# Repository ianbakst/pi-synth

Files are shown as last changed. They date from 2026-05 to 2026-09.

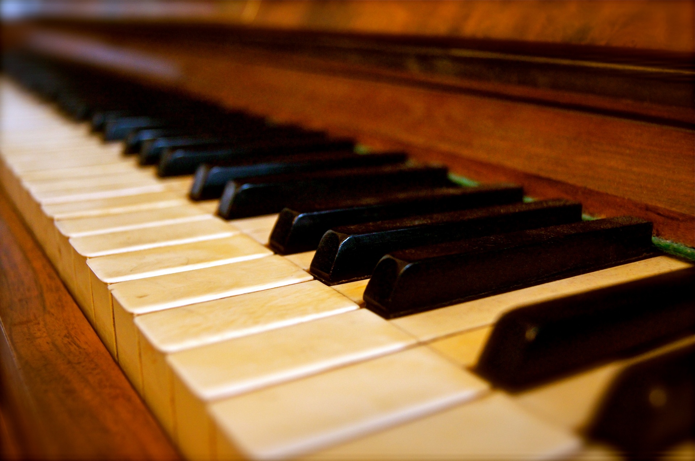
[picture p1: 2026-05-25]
src/synth_ui/assets/images/splash.jpg

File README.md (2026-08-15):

# pi-synth

A dedicated, hot-swappable MIDI instrument built on a Raspberry Pi 4. Multiple
audio engines — FluidSynth, sfizz, setBfree, Dexed, Pianoteq — run behind a common
interface and are switched at runtime from a 3.5" touchscreen. Audio flows over
JACK to a PCM5102A I2S DAC; a USB MIDI keyboard is bridged into JACK by
`a2jmidid`. The Python UI is a **control plane only** — it patches the JACK graph
and starts/stops engines; notes and samples never pass through Python.

On a non-Pi machine the UI runs windowed for development (`IS_PI` is auto-detected).

## Hardware

| Component | Part |
|---|---|
| SBC | Raspberry Pi 4 (64-bit, PREEMPT_RT kernel) |
| DAC | Teyleten Robot PCM5102A (I2S, `hifiberry-dac` overlay) |
| Display | 3.5" 800×480 touchscreen (ft5x06) |
| MIDI input | USB MIDI keyboard(s) — hot-plug supported |

## Provisioning: flash the custom image

The supported way to build a unit is to flash the **custom Raspberry Pi OS image**
built by pi-gen — it bakes in the RT kernel, the JACK/engine stack, all systemd
services, and this app, and boots straight to the UI with nothing to run by hand.

See **[os-image/README.md](os-image/README.md)**. In short: drop your prebuilt
RT kernel `.deb` in `os-image/kernel/`, then `cd os-image && ./build.sh`.

## Development

```bash
uv sync
uv run python -m synth_ui.main   # windowed UI (dev machine)
uv run pytest                    # tests
uv run ruff check src/           # lint
```

### Iterating on a running Pi

Once a unit is flashed, push app changes to it without reflashing:

```bash
./deploy.sh <pi-host>    # rsync src -> /home/synth/synth, run tests, restart synth-ui
```

## Project structure

```
src/synth_ui/          the control-plane app
  main.py              entry point (python -m synth_ui.main)
  config.py            paths, screen, ports, colors
  clients/             engine_manager (switches engines, patches JACK), engine
                       (Engine/ProcessEngine/ModHostEngine), jack_graph,
                       audio_devices, mod_host/synth clients, voice
  ui/                  pygame touchscreen UI (screens, components)
scripts/
  start-jack.sh        pick the ALSA card + exec jackd (jack.service's ExecStart)
systemd/               the 7 units (jack, a2jmidid, mod-host, synth-ui, ... )
instruments/voices.json  the voice manifest
os-image/              pi-gen custom image build (provisioning)
hardware/              DAC HAT / enclosure design files (Git LFS)
```

See [AUDIO_UPGRADE.md](AUDIO_UPGRADE.md) for the multi-engine audio architecture.

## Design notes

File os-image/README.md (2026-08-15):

# pi-synth OS image (pi-gen)

Builds a custom Raspberry Pi OS image that boots straight into the pi-synth
appliance — RT kernel, JACK/engine stack, all seven systemd services, and the UI
— with nothing to run by hand after flashing. This replaces the old `setup.sh`
provisioning of a stock Lite card.

It's a thin custom stage (`stage-pi-synth/`) layered on top of pi-gen's minimal +
Lite stages (`stage0`–`stage2`); the desktop stages 3–5 are never referenced.
pi-gen itself is a **build dependency `build.sh` fetches on demand**, pinned to an
exact commit on `bookworm-arm64`, into the gitignored `os-image/pi-gen/` — it is
never modified or committed; our stage lives here and is fed to pi-gen by
absolute path.

## Prerequisites

- **Docker** running (Docker Desktop on macOS; Apple Silicon builds the arm64
  target natively and fast — Intel falls back to qemu).
- Your **PREEMPT_RT kernel artifacts** harvested from a working RT board in
  [`kernel/`](kernel/) — layout and required filename are board-specific
  (`kernel8.img` for pi4, `kernel_2712.img` under `kernel/cm5/` for cm5). See
  [kernel/README.md](kernel/README.md).
- *(Optional)* **WiFi** — `cp wifi.env.example wifi.env` and fill in your SSID +
  password. If `wifi.env` is present, stage `07-wifi` bakes a NetworkManager
  profile into the image so the Pi joins WiFi on first boot. `wifi.env` is
  gitignored (it holds your password). Absent = no WiFi preconfigured; Ethernet
  still works.

## Build

```bash
git clone https://github.com/ianbakst/pi-synth.git
cd pi-synth
# harvest your RT kernel into os-image/kernel/ (see kernel/README.md)
cd os-image
./build.sh                       # pi4 (default): fetches + pins pi-gen, then builds
PI_SYNTH_BOARD=cm5 ./build.sh    # or build for the CM5 instead
```

`build.sh` clones pi-gen (pinned) into `os-image/pi-gen/` the first time — no
submodule, no `--recursive` needed.

The image lands in `os-image/pi-gen/deploy/` as `*-pi-synth.img.xz` (pi4) or
`*-pi-synth-cm5.img.xz` (cm5) — the board-specific name means both can be built
without one overwriting the other.

### Iterating

A full build is ~30–45 min. To resume after a failed/edited stage instead of
rebuilding from scratch:

```bash
CONTINUE=1 ./build.sh
```

To skip an expensive stage you've already built while iterating on a later one,
drop a `SKIP` file in it, e.g. `touch stage-pi-synth/02-audio-stack/SKIP`
(remove it before a real build). See the pi-gen README for the full
`SKIP`/`SKIP_IMAGES` workflow.

## Flash & verify

Flash `deploy/*-pi-synth.img.xz` with Raspberry Pi Imager (or `dd`). On first
boot it should come up on the touchscreen with no manual steps. Sanity checks
over SSH (`synth` / password from `config`):

```bash
uname -v                                   # contains PREEMPT_RT
aplay -l | grep -i hifiberry               # DAC present
systemctl is-active jack a2jmidid mod-host synth-ui   # all active
```

Then confirm a USB keyboard plays and switching voices works. For the realtime
floor: `cyclictest -m -Sp99 -i200 -l100000`, and watch JACK's xrun counter over a
sustained voice-switching session.

## What the stage does (ported 1:1 from the old setup.sh)

| Stage | Responsibility |
|---|---|
| `00-base-packages` | apt packages + jackd2 RT-limits debconf preseed |
| `01-realtime-kernel` | install harvested RT kernel (board-specific filename, see `PI_SYNTH_BOARD`) + modules, `depmod` |
| `02-audio-stack` | build + install mod-host and sfizz (LV2) from source |
| `03-boot-config` | `config.txt` (HiFiBerry DAC, disable BT/onboard audio, HDMI audio) + `cmdline.txt` (isolate cores 1,2,3; quiet boot) |
| `04-pi-synth-app` | vendor app to `/home/synth/synth`, dirs, `default.sf2`, sudoers |
| `05-services` | install 7 units; enable always-on ones; mask stock fluidsynth |
| `06-system-tuning` | RT limits, RAM-only journald, no swap, disable jitter services |

CPU governor and IRQ affinity are applied at runtime by `cpu-performance.service`.

## Configuration

Edit [`config`](config): first user (`synth`), hostname, locale/timezone,
WiFi country, SSH pubkey, image compression. The `synth` username is load-bearing
(hardcoded in the units and `config.py`) — don't change it.

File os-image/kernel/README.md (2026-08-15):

# RT kernel artifacts

The image bakes a **PREEMPT_RT kernel harvested from a working RT board** (there
is no official prebuilt RT kernel to download for Raspberry Pi OS). Drop the
harvested files here — they are **not** committed (`os-image/.gitignore` excludes
them at any depth under `kernel/`; they're large and board-specific). Use Git LFS
if you want them tracked.

Layout is per-board, selected by `PI_SYNTH_BOARD` (`pi4` default, or `cm5`) when
running `../build.sh` — see its usage comment. **pi4** keeps the original flat
layout (unchanged, for backward compatibility); **cm5** lives in its own
subdirectory since it needs a different kernel filename and is a different SoC
generation (BCM2712, not BCM2711 — a from-scratch RT build, not a re-harvest of
the pi4 one).

## Expected layout

```
kernel/
├── kernel8.img            # pi4 RT kernel image                 (required for pi4)
├── modules/<KVER>/        # pi4 /lib/modules/<KVER> tree         (required for pi4)
├── dtb/*.dtb               # pi4 device trees                    (optional)
├── overlays/*.dtbo         # pi4 overlays                        (optional)
└── cm5/
    ├── kernel_2712.img     # cm5 RT kernel image                 (required for cm5)
    ├── modules/<KVER>/     # cm5 /lib/modules/<KVER> tree         (required for cm5)
    ├── dtb/*.dtb            # cm5 device trees                    (optional)
    └── overlays/*.dtbo      # cm5 overlays                        (optional)
```

`<KVER>` is your kernel version string (`uname -r` on the board), e.g.
`6.12.30-rt-v8+` (pi4) or `6.12.96-v8-16k+` (cm5 — note PREEMPT_RT doesn't
always appear in the version *string* itself; confirm with `uname -v` instead,
which should contain `PREEMPT_RT`). The modules tree **must** match the kernel
image, or the kernel boots but half its drivers won't load — always key off
`uname -r`.

Note the boot filename genuinely differs by SoC generation, not just by
convention: BCM2711-and-earlier (pi4) boards default to `kernel8.img`;
BCM2712 (Pi 5/CM5-generation) boards default to `kernel_2712.img`. Installing
under the wrong filename means the firmware silently keeps booting whatever it
already had — stage `01-realtime-kernel` installs to the correct name per
board automatically, but a manual local install (to test-boot before
harvesting) needs the right name too.

## How to harvest (run on your Mac)

### pi4 (flat layout, unchanged)

```bash
PI=synth@192.168.1.125                 # your Pi's user@IP
KVER="$(ssh "$PI" uname -r)"
cd os-image/kernel

scp "$PI:/boot/firmware/kernel8.img" ./kernel8.img
mkdir -p dtb overlays
scp "$PI:/boot/firmware/*.dtb"           ./dtb/
scp "$PI:/boot/firmware/overlays/*.dtbo" ./overlays/
# rsync (not scp -r): copies the dangling build/source symlinks safely
rsync -a --exclude=build --exclude=source "$PI:/lib/modules/$KVER" ./modules/
```

### cm5 (subdirectory layout)

```bash
PI=synth@192.168.1.126                 # your CM5's user@IP
KVER="$(ssh "$PI" uname -r)"
mkdir -p os-image/kernel/cm5
cd os-image/kernel/cm5

scp "$PI:/boot/firmware/kernel_2712.img" ./kernel_2712.img
mkdir -p dtb overlays
scp "$PI:/boot/firmware/bcm2712*.dtb"    ./dtb/
scp "$PI:/boot/firmware/overlays/*.dtbo" ./overlays/
rsync -a --exclude=build --exclude=source "$PI:/lib/modules/$KVER" ./modules/
```

## How it's used

Stage `01-realtime-kernel` overwrites the board's default kernel filename
(`kernel8.img` for pi4, `kernel_2712.img` for cm5 — the base image already sets
`arm_64bit=1` with no custom `kernel=`, so the firmware loads the default by
name — no `config.txt` change needed) with your RT image, installs the modules
tree to `/lib/modules/<KVER>`, refreshes the dtbs/overlays if present, and runs
`depmod -a <KVER>` in-chroot to regenerate dependency metadata.

To confirm after flashing: `uname -v` on the booted board should contain
`PREEMPT_RT`, and `lsmod` should show your drivers loading.

## Custom kernel name?

If the board's `config.txt` set a custom `kernel=` (check with
`grep kernel= /boot/firmware/config.txt`), the harvested image may not be named
`kernel8.img`/`kernel_2712.img` — stage `01` still installs the single `*.img`
it finds in the board's kernel directory under that board's expected default
name, which the firmware boots by default absent a `kernel=` override.

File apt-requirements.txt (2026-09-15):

python3-pygame
fluidsynth
jackd2
a2jmidid
# Kept for its LV2 bundle (/usr/lib/lv2/b_synth), which IS the Hammond now.
# The standalone binary it also installs is no longer run — setbfree.service
# was retired when the organ moved into mod-host. Do not drop this package.
setbfree
build-essential
cmake
libsndfile1-dev
libjack-jackd2-dev
liblilv-dev
libreadline-dev
# Keep in sync with os-image/stage-pi-synth/00-base-packages/00-packages — that
# list provisions a fresh image, this one is what deploy.sh installs onto a
# running board. They had drifted: the LV2 plugin packages below were only in
# the image list, so a deployed-to board could be missing the plugins the voice
# catalog names.
# LV2 plugins: effects, and the mda/Calf instruments in voices.json.
calf-plugins
zam-plugins
x42-plugins
mda-lv2
# lv2ls / lv2info: the UI greys out voices whose plugin isn't installed, and
# verify_voices --inspect reads a plugin's control symbols + patch properties.
lilv-utils
# --- Instrument plugins ---------------------------------------------------
# amsynth: a two-oscillator analog model. This is the one for the 80s brass
# poly (the Van Halen "Jump" sound is an Oberheim OB-Xa: detuned saws, fast
# filter envelope). mda JX10 can approximate it; amsynth gets much closer and
# ships presets.
amsynth
# zynaddsubfx-lv2: additive/subtractive/pad engine with a large preset bank —
# breadth for pads, bells and leads that the mda and Calf synths don't cover.
zynaddsubfx-lv2
# Level calibration (synth_ui.tools.calibrate_levels).
# aplaymidi (alsa-utils) plays the passage; jack-smf-player would be the
# direct route but jack-smf-utils is no longer packaged for Debian.
jack-capture
alsa-utils
ffmpeg

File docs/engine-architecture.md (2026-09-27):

# Engine architecture & audio graph

How the pi-synth control plane switches instruments and routes audio, and the
roadmap to get there. This reconciles the design in `.claude/plan.md` with the
realities of the running system (systemd-managed RT engines, mod-host, the
harvested-kernel image).

## Principles (unchanged from the design)

- **No Python in the note/audio path.** Notes flow `a2jmidid`/`ttymidi` (USB /
  DIN) `→ JACK → engine → DAC` in realtime-thread space. Python only issues
  *control-plane* actions:
  start/stop an engine, load a preset, and patch the JACK graph.
- **The app never manages JACK or RT scheduling itself.** JACK, mod-host, and
  a2jmidid run as systemd services (see `../systemd/`). Engines get their RT
  priority + core pinning from their unit files (`chrt`, `taskset`,
  `LimitRTPRIO`), never from Python.

## Key decision: switch at the systemd level, orchestrate in Python

The design doc had Python `Popen` the engine *and* forbade Python from setting RT
priority — a contradiction (nobody grants the spawned engine `chrt -f 80`). We
resolve it by keeping engines as **systemd services** and putting only the
*orchestration* in Python:

- `ProcessEngine.start()` → `systemctl start <unit>` (not `Popen`). The unit file
  supplies RT priority/affinity/memlock.
- `ModHostEngine.start()` → `add <uri> <instance>` over mod-host's socket
  (mod-host is already an RT JACK client).
- The `Engine` interface, `ENGINE_REGISTRY`, connect-before-disconnect ordering,
  panic-before-teardown, and readiness polling all live in Python.

This is not slower in any way that matters: a switch's cost is dominated by the
engine's own cold-start (soundfont load, JACK port registration); `systemctl`
adds tens of ms of orchestration that is inaudible next to that, and steady-state
audio latency is identical. systemd also buys supervision, journald logging, and
declarative limits. So the choice is made on robustness, not speed.

## CPU core allocation (Pi 4, 4 cores)

One purposeful role per core. Cores 1,2,3 are isolated
(`isolcpus=1,2,3 nohz_full=1,2,3 rcu_nocbs=1,2,3` in `cmdline.txt`); core 0 runs
the normal scheduler.

| Core | Role | Isolated | Pinned via |
|---|---|---|---|
| **0** | OS + UI + all general IRQs | no | `synth-ui.service` `taskset -c 0` `Nice=5`; `cpu-performance.service` sets IRQ mask 1 |
| **1** | JACK backend (audio heartbeat) + MIDI bridges + audio IRQ | yes | `jack.service` / `a2jmidid.service` / `ttymidi.service` `taskset -c 1`; audio IRQ steered by `cpu-performance.service` |
| **2** | Active instrument engine | yes | `fluidsynth-engine`/`setbfree`/pianoteq `taskset -c 2`; `mod-host` also uses this core (see below) |
| **3** | Currently: mod-host overflow. Later: effects | yes | `mod-host` `taskset -c 2,3` today; a *second* mod-host for effects — **Phase 3, not yet built** — would also want this core |

Deliberately **not** core 0: that's where `isolcpus`/`nohz_full` route every general
IRQ, kernel housekeeping thread, and the UI, on purpose — audio sharing it would
be exposed to exactly the noise the isolation exists to prevent, and risks
starving the same core SSH/D-Bus run on. Confirmed not worth it on hardware (see
"Active instrument engine" below).

**Why this, and what it buys:** the chain `engine → effects → DAC` is *serial*, so
separate cores don't run stages in parallel — the win is **jitter isolation and
headroom** (each stage uncontended → lower buffers, fewer xruns under sustained
load), not throughput. RT-correct for an instrument.

**"Active instrument engine" is enforced to mean exactly one process, always.**
mod-host used to be always-on (enabled at boot like jack/a2jmidid). Hardware
validation found that having it resident on core 2 at the same time as another
active engine (e.g. fluidsynth) causes continuous JACK XRuns — `journalctl -u
jack | grep -c XRun` kept climbing indefinitely even with both engines fully
idle, because two `chrt -f 80` RT clients were contending for one isolated core
every single 2.67ms period. Stopping one of the two immediately took the xrun
count to a steady 0. Fix: mod-host is now on-demand, exactly like
`fluidsynth-engine`/`setbfree` — `ModHostEngine.start()`/`stop()`
(`src/synth_ui/clients/engine.py`) start/stop `mod-host.service` around the
add/remove-plugin socket calls, and the unit is no longer `systemctl enable`d
at boot (`os-image/stage-pi-synth/05-services`) nor `PartOf=jack.service` (that
would have force-restarted it — i.e. started it even when it shouldn't be
running — on every audio-device change).

**mod-host caveat:** mod-host processes all its plugins in one thread, so a single
mod-host can't split instrument from effects onto separate cores. **Core 3's role
has changed from the original plan**: rather than sit idle waiting for Phase 3,
the instrument mod-host now spans cores 2+3 (`taskset -c 2,3`), because a large
SFZ's sample streaming/decode work was contending with JACK's own callback
thread for core 2 alone — a real, measured problem (below), not a hypothetical
one. **This means Phase 3's plan needs revisiting**: a second mod-host wanting
sole use of core 3 for effects would recreate the exact single-core contention
this fix just solved. Options when that's built: give effects core 3 back and
accept the instrument-side regression, find a third core to shuffle things onto,
or reconsider whether effects need a dedicated core at all. Not decided — flag
this when Phase 3 effects routing actually starts.

**Validated on hardware:**
- `journalctl -u jack | grep -c XRun` flat at 0 with the active instrument engine
  alone on core 2, sustained idle.
- mod-host on core 2 alone, streaming a large SFZ (641 regions) under sustained
  play: ~180 xruns/min despite only ~40-60% CPU — confirming RT audio is
  deadline-per-callback bound, not average-utilization bound; CPU headroom does
  not predict xrun-freedom when a core is shared or contended.
- Same scenario, mod-host expanded to cores 2,3 (`taskset -c 2,3`, still no
  `chrt`): ~65 xruns/min — real improvement, not a full fix. The remainder was
  attributed at the time to first-touch SD sample reads; the CM5 measurements
  below found two causes that sit *behind* those reads rather than being them.
- Re-adding `chrt -f 80` to mod-host on 2,3 was tested and made things
  dramatically worse (~14,500 xruns/min, audible buzzing): it raised mod-host's
  decode threads above JACK's own callback-thread priority, causing them to
  preempt it — a priority inversion. Confirms mod-host should stay affinity-only,
  no `chrt`, matching the SIGKILL/RCU-stall wedge found earlier under heavy load.

**Remaining sfizz xruns, CM5 (2026-09).** Test: a fixed two-minute pedalled
Salamander passage (1,440 notes, seeded) sent through `Midi Through` with the
DAC disconnected, counting JACK `Process error` cycles.
- **Priority inversion, 92 xruns → 2-25.** sfizz raises its own disk-streaming
  threads to `SCHED_RR 50` when `RLIMIT_RTPRIO` allows it. mod-host had
  `LimitRTPRIO=80`, so it did, and every JACK client thread in mod-host runs at
  `FIFO 5` (jackd's default `-P 10`, minus 5 — the `chrt -f 90` in
  `start-jack.sh` lifts only jackd's idle main thread; its audio thread is at
  10). Each note past its preload had a loader decoding the rest of the sample
  ahead of every audio thread on cores 2-3. `LimitRTPRIO=10` makes sfizz's
  request fail quietly.
- **Page faults in real-time threads, 2-25 → 0.** Every remaining xrun lined up
  with a page fault in a mod-host real-time thread (sampled per thread every
  100 ms), and every such fault with an xrun. The loaders' constant mapping and
  unmapping holds the mmap lock that even a minor fault needs. mod-host doesn't
  `mlockall`, so `scripts/mlockall_preload.c` does it via `LD_PRELOAD`: five
  runs, zero xruns, zero faults. Cost: mod-host's memory stays at its
  high-water mark (~1.65 GB with Salamander, ~2 GB left free).

Still to validate: `cyclictest -m -Sp99 -i200 -l100000` on cores 1,2,3 for the
raw RT floor, and the xrun counter over a sustained voice-*switching* session
(not just idle) now that mod-host's lifecycle changed.

## The JACK graph (data plane)

```
 a2j:<keyboard capture>   (USB) ─┐
                                 ├──MIDI──▶ [ velocity filter ]  ← optional, lazy
 ttymidi:MIDI_in     (5-pin DIN) ─┘                   │
                                                      ▼
                                          <active engine>:midi_in
                                                  │ audio out
                                                  ▼
                              [ effects rack (mod-host) ]   ← optional, persistent
                                         │
                                         ▼
                                 system:playback_1/2  (HiFiBerry DAC)
```

### MIDI ingress: two transports, one rule

USB and DIN are physically different transports and need different bridges —
`a2jmidid` lifts ALSA-seq hardware ports into JACK, `ttymidi` (mod-audio's
`mod-ttymidi`) reads the UART0 byte stream. Both are C, RT-scheduled, on core 1;
neither puts Python in the note path.

This also closed a latent bug. `a2jmidid -e` does **not** mean "hardware only" —
it is opt-*in* for hardware ports and still exports software ALSA-seq clients
alongside them. The previous rule ("any `a2j:` port whose name contains
`capture`") therefore also matched ALSA's `Midi Through` loopback and wired it
into the active instrument on every voice switch. Harmless — nothing feeds it —
but junk in the graph; the physical flag excludes it.

What keeps that from becoming a pile of special cases is that the control plane
never names either of them. Both bridges register their JACK ports as
`JackPortIsPhysical | JackPortIsTerminal` — the claim "this is a real jack on the
box, not a software port" — so `JackGraph.keyboard_midi_sources()` matches on
exactly that: **a physical MIDI source port**. `EngineManager._wire()` patches
every one of them to the active instrument, so both keyboards play the current
rig, and a third transport (a second DIN, BLE/RTP-MIDI) needs no code change.

**Confirmed on the CM5** (2026-09-02), which is why the config looks like it
does: with `dtparam=uart0=on`, `/dev/ttyAMA0` appears as `root:dialout` (so the
`synth` user reaches it via the group pi-gen already grants — no unit-level
group grant needed), GPIO14/15 mux to `TXD0`/`RXD0`, and the RP1 UART accepts a
true 31250 baud through `TCSETS2`/`BOTHER` — verified against a 38400 control
request, so no `midi-uart0-pi5` clock overlay is needed. Note `stty` *cannot*
express 31250 (it errors "invalid argument"); that's a coreutils limitation, not
a hardware one, so don't read it as a fault.

**Not yet confirmed:** bytes on the wire. No MIDI-out gear was on hand when this
landed, so the DIN jack, its opto-isolator, and the achieved divisor are unproven
end to end. Everything up to and including "the JACK port exists and the UI
patches it into the active rig" is verified. See the deferred check at the bottom
of this section.

The DIN jack is wired to UART0 RX (GPIO15) only — MIDI IN, no OUT.
`ttymidi:MIDI_out` exists but is left unconnected. Setup lives in
`os-image/stage-pi-synth/03-boot-config/00-run.sh` (enable `uart0`, and keep the
kernel's serial console *off* those pins) and `systemd/ttymidi.service`
(31250 baud, set directly via `BOTHER`/`TCSETS2` rather than with the
`midi-uart0` clock-fudge overlay).

**Deferred check — do this when a MIDI controller is available.** Play into the
DIN jack and confirm notes sound through the active rig. If they don't, isolate
with `python3 ~/synth/scripts/midisniff.py` (a `BOTHER`-mode raw byte dump —
`stty` can't set this rate): note-on triples that track your playing mean the
wire is fine and the fault is above it; garbage means the divisor is off after
all, so add
`dtoverlay=midi-uart0-pi5` and switch `ttymidi.service` to `-b 38400`; silence
means wiring or the opto-isolator, DIN pins 4/5 first. Without a controller, a
jumper from GPIO14 to GPIO15 loops TX back to RX and exercises the same path —
but check it won't fight the opto's output stage on that net first.

There is a simpler shape available later: the kernel's `snd_serial_generic`
driver (`compatible = "serial-midi"`) would make the DIN port a real ALSA rawmidi
card, so `a2jmidid` alone would carry both transports and `ttymidi.service` could
be deleted. It is not enabled in `bcm2711_defconfig`/`bcm2712_defconfig` and so is
absent from the harvested RT kernel; taking it would mean a kernel rebuild plus a
hand-written overlay. Worth doing on the next kernel build, not before — and the
port rule above already covers that world unchanged, since the DIN port would
then simply appear under `a2j` as physical.

Per-engine JACK identities (discover with `jack_lsp` / `jack_lsp -t` on the Pi —
do not hardcode without checking):

| engine | kind | MIDI in | audio out |
|---|---|---|---|
| fluidsynth | process (`fluidsynth-engine.service`) | `fluidsynth*:midi*` | `fluidsynth*:l/r` (needs `audio.jack.autoconnect=1`) |
| setBfree | process (`setbfree.service`) | `setBfree:midi_in` | `setBfree:out_left/right` |
| sfizz / dexed | mod-host plugin (`mod-host.service`) | `mod-host:midi_in` | mod-host plugin audio out |
| pianoteq | process (future `pianoteq.service`) | `Pianoteq*:midi*` | `Pianoteq*:out_*` |

**Known gap this design closes:** nothing currently connects a mod-host
instrument's *audio* output to `system:playback`, and `fluidsynth -a jack` does
not autoconnect by default — so mod-host voices are likely silent today and
fluidsynth relies on luck. Audio patching becomes an explicit EngineManager
responsibility (Phase 2), and fluidsynth gets `audio.jack.autoconnect=1` now
(Phase 1).

### Fixed velocity — `VelocityFilter`

A rig can play every note at one velocity instead of as struck
(`Rig.fixed_velocity`, toggled from the rig editor's header). Since notes never
pass through Python, that means rewriting a byte of every note-on in the RT
path, so it is an LV2 plugin in mod-host — x42's
`midifilter#velocityscale`, which ships in `x42-plugins` (already in
`00-packages`; nothing new to build).

It is the MIDI-side mirror of the master chain: a single-purpose stage the user
never assembles, sitting at the head of the path rather than the tail, at
mod-host instance **100** (instruments 0-9, effects 10-89, master 90+, MIDI
filters 100+). `EngineManager._midi_sources()` answers "what feeds the
instrument" the way `_sinks()` answers "where does its audio go", so neither
`_wire` nor `_unwire` has to know whether a filter exists.

Three decisions worth not re-litigating (the reasoning is in
`clients/velocity_filter.py`):

- **Loaded lazily**, unlike the master chain — a board that never uses this
  never carries the plugin. The master chain is always needed; this isn't.
- **Off is identity parameters, not removal.** `onmin=1, onmax=127` is an exact
  identity in midifilter's arithmetic, and `onmin == onmax == V` pins every
  note-on to V. Removing the plugin on every toggle would rebuild the
  keyboard→instrument leg each time, and while both the direct and the filtered
  edge exist every note sounds twice.
- **`bypass` is not used for it.** mod-host's bypass copies input buffers to
  output, which is defined for audio; whether it forwards MIDI is not something
  to bet the keyboard on.

**Not yet measured on hardware:** the added latency. The filter is a second JACK
client in series, but both it and the instrument live in the same mod-host
process and JACK runs serial clients in dependency order within one period, so
the expected cost is ~0 — worth confirming with `tools/midi_latency.py` before
trusting it in a set, given how much trouble MIDI latency has already been on
this box (see the FP-10 note in CLAUDE.md).

## Audio device selection (which card JACK opens)

A *different* discovery layer from `JackGraph`: which physical sound card jackd
opens. JACK binds one device at startup and presents uniform `system:playback_*`
ports regardless — so the graph patching above is card-agnostic; only jackd's
startup device changes.

- **`AudioDevices`** (`clients/audio_devices.py`) enumerates ALSA playback cards
  from `aplay -l` by stable id (`hw:<id>`, never index), and resolves the
  effective device by precedence: **valid saved choice → HiFiBerry → first card →
  none**.
- **`scripts/start-jack.sh`** is `jack.service`'s ExecStart. It applies that same
  precedence at boot and falls back to jackd's **dummy backend** if no card is
  present — so jackd (and the UI) always come up and the user can recover from a
  missing/renamed card.
- Selection persists in `~/.synth-audio-device` (config `AUDIO_DEVICE_FILE`),
  written by the UI. Absent = auto-detect (the out-of-box default).
- Changing the card = **restart jackd** (not a live patch), which rebuilds the
  stack: `mod-host`/`a2jmidid` are `PartOf=jack.service` so they cycle with it;
  `synth-ui` is `Wants=` (not `Requires=`) so the control-plane UI survives the
  restart it triggered, then reloads the active voice to re-patch.
- **Next:** a UI "Audio" screen (list cards → select → write file → `sudo
  systemctl restart jack.service` → reload voice; sudoers already scoped for it),
  and sample-rate / buffer-size tuning on the same screen.

## The Python layer (target shape)

```
src/synth_ui/clients/
├── jack_graph.py     # JackGraph: discover ports + connect/disconnect (subprocess
│                     #   jack_lsp/jack_connect — zero new deps; swappable for
│                     #   python-jack later). connect-before-disconnect lives here.
├── engine.py         # Engine ABC, ProcessEngine (systemctl), ModHostEngine (socket)
├── engine_manager.py # EngineManager: ENGINE_REGISTRY, switch_to(), panic ordering,
│                     #   MIDI + AUDIO patching. Public API (load_voice/list_presets/
│                     #   select_preset/set_gain/is_connected) stays stable for the UI.
├── mod_host_client.py  # (exists) mod-host socket protocol
├── synth_client.py     # (exists) FluidSynth TCP shell
└── voice.py            # (exists) Voice + manifest
```

`Engine` interface (adds `audio_out_ports` and `load` to the design's version):

```python
class Engine(ABC):
    key: str                       # JACK-source identity for same-source detection
    def start(self) -> None: ...
    def stop(self, timeout=2.0) -> None: ...
    def is_ready(self) -> bool: ...        # poll: ports present in the JACK graph
    def panic(self) -> None: ...           # all-notes-off, best effort, before teardown
    def load(self, voice: Voice) -> bool: ...   # load SF2/SFZ/patch into the running engine
    @property
    def midi_port(self) -> str: ...
    @property
    def audio_out_ports(self) -> list[str]: ...
```

**Reality-driven divergence:** sfizz and dexed are *not* separate engines — they
share mod-host's single plugin slot and its stable JACK ports. They collapse into
one `ModHostEngine` whose `load(voice)` swaps the plugin (remove+add if the URI
differs) and `patch_set`s the instrument file (an LV2 patch property — sfizz's
SFZ path is atom-based, not a control port; `param_set` silently no-ops on it).
Switching sfizz↔dexed is therefore an
in-mod-host swap with **no JACK re-patch** (the ports don't move). The manager
uses `engine.key` (`fluidsynth`/`setbfree`/`pianoteq`/`modhost`) to decide
in-place reload vs. full switch.

`EngineManager.switch_to(voice)` (full switch path):
1. `new.start()`; poll `new.is_ready()` with a bounded timeout → surface a clear
   UI error on timeout.
2. `new.load(voice)`.
3. `graph.connect(keyboard_midi → new.midi_port)` and
   `graph.connect(new.audio_out_ports → sink)` — **before** touching the old one.
   (`sink` = effects-rack input if effects are loaded, else `system:playback`.)
4. If an engine was active: `old.panic()`, then disconnect old MIDI/audio ports
   **except any shared with new** (protects mod-host's shared ports), then
   `old.stop()`.

Same-`key` load (e.g. fluidsynth SF2 → SF2) skips all patching: just
`active.load(voice)`.

## Effects rack (mod-host) — `EffectsRack`

**Resolved:** effects run in the *same* mod-host instance as the active
instrument (cores 2+3), not a second process on its own core. The original
two-instance plan (`systemd/mod-host-fx.service`, socket 5556, core 3) is
superseded — reasoning, not just a resource conflict:

- **Separate cores never bought parallelism here, because there wasn't any to
  buy.** Instrument → effects is a serial *data dependency*: effects can't
  start processing a period until the instrument's output for that period
  exists. Total compute (instrument + effects) has to fit in one ~2.67ms
  deadline no matter which core(s) either stage runs on — there is no
  independent work to overlap. Contrast with why cores 2+3 *did* help the
  instrument alone: mod-host's LV2 "worker" threads (e.g. sfizz's own sample-
  streaming) are genuinely independent of that period's callback and benefit
  from a free core to run on. Effects DSP has no such independent piece — it's
  on the critical path by definition.
- Practical upshot: a second mod-host on its own core would not have isolated
  effects from instrument-side latency the way the original plan assumed. It
  would have added a second full LV2-world-scan cold-start (the exact
  readiness race already fixed once for the instrument mod-host) and a second
  process that could wedge, for a benefit that doesn't materialize for this
  specific pipeline shape.
- **This also resolves one of the two hardware unknowns below**: mod-host's
  per-instance port-naming convention (`effect_<instance>`) is no longer a
  *separate* fx-mod-host question — it's the same convention already confirmed
  on hardware for the instrument mod-host (`effect_0:control` /
  `effect_0:out_left/right`, found while debugging sfizz). Effects loaded at
  instances 10+ in the same process follow the identical naming; nothing new
  to verify there. The *other* unknown (§ below) — whether a real effect
  plugin's DSP fits the shared budget without pushing xruns up — is still a
  hardware question, now the only one.

`clients/effects_rack.py` (`EffectsRack`) manages the chain:

- Effect plugins live at mod-host instances **`10+`** (instruments use `0–9`),
  loaded once and **persistent across instrument switches**.
- `add(uri)` appends to the chain and `_rechain()`s: `fx[0].out → fx[1].in → … →
  fx[N].out → system:playback`. It tears down its prior wiring first (tracked in
  `_wired`) so a stale "old last → DAC" edge never lingers. `remove`/`clear`
  likewise re-chain. Python only patches; DSP is in mod-host.
- `input_ports()` (first effect) / `output_ports()` (last effect) let the manager
  route `active_instrument.out → rack.input`; the rack→DAC leg never moves.
- **Watch the xrun counter as each effect is added** — this is now the real
  budget check, since effects share the instrument's cores and its per-period
  deadline. Add one at a time, measure, don't assume a chain that worked with
  N-1 effects still has headroom for N.
- **Not** running `mod-ui` (MOD's web pedalboard editor) — too heavy/jittery for a
  touchscreen appliance. Drive mod-host directly.

**One open question left that needs the board:** does real effect DSP (a
reverb, an EQ, a compressor) actually fit the shared per-period budget
alongside a loaded instrument, and how many/how heavy before xruns climb? No
longer an architecture question — just needs measuring on real hardware, the
same way the instrument-alone budget was measured tonight (~180 → ~65
xruns/min moving 2→cores 2,3; a similar live test applies here per effect
added).

**Still deferred, now purely because nobody's built it yet, not because of an
open unknown:** `EngineManager` routing (instrument → rack → DAC, and
re-wiring the instrument when the rack goes empty↔non-empty) and the UI
effects screen — in progress, see the plan for "Wire the effects rack into
EngineManager + UI". `mod-host-fx.service` (the old, superseded two-instance
design) has been deleted.

## Startup: a working instrument on boot

`HomeScreen` already loads the restored voice on startup — but only if
`~/.synth-state` exists, so a freshly flashed card plays nothing until you tap a
voice. Fix: fall back to a configured `DEFAULT_VOICE` (the fluidsynth "General
MIDI" voice — its `default.sf2` is guaranteed present in the image, and with
autoconnect its audio reaches the DAC). So: boot → splash → default GM voice
loads → keyboard plays, no interaction needed.

## Phased roadmap

**Phase 1 — working instrument on startup (low risk, no hardware needed to write):**
- `fluidsynth-engine.service`: add `-o audio.jack.autoconnect=1`.
- `DEFAULT_VOICE` in config; `app.py` uses saved-state-or-default.
- Rebuild → boot → GM piano playable with no touchscreen interaction.

**Phase 2 — engine-over-systemd + full audio graph (needs the Pi in the loop):**
- `JackGraph`, `Engine`/`ProcessEngine`/`ModHostEngine`, `EngineManager` rework
  with MIDI **and** audio patching + panic + connect-before-disconnect.
- Fixes mod-host (sfizz/dexed) silence by explicitly wiring their audio to the
  DAC. Retire `scripts/engine-manager.sh` / `midi-connect.sh` (Python
  orchestrates via `systemctl` + `jack_*`).
- *Validated on hardware:* found and fixed mod-host being always-on causing
  continuous core-2 XRuns (see "Active instrument engine" note above) — it's
  now on-demand like the other engines.
- Still to validate: no gap on switch, panic silences held notes, sustained
  *switching* produces no xruns (idle is now confirmed clean; switching load
  hasn't been re-tested since the mod-host lifecycle change).

**Phase 3 — effects rack** (see "Effects rack" above):
- *Done (increment 1):* effect LV2 packages in `00-packages`
  (`calf-plugins`, `zam-plugins`, `x42-plugins`, `mda-lv2`); `mod-host-fx.service`
  (core 3, installed not enabled); `EffectsRack` class + tests.
- *Needs the board:* confirm the fx mod-host client name and the effect
  audio-port naming (the two open questions above), then wire `EngineManager`
  routing (instrument → rack → DAC) and the UI effects screen.
- Watch the xrun budget on core 3 as effects are added.

## Engine build status (image `02-audio-stack`)

- **sfizz** — LV2 plugin built from `sfztools/sfizz-ui` (NOT `sfztools/sfizz`,
  which is only the core lib + a JACK client we don't use). Verified on hardware:
  installs `/usr/local/lib/lv2/sfizz.lv2`, URI `http://sfztools.github.io/sfizz`
  (matches `_MODHOST_PLUGINS` in `clients/engine.py`).
- **Dexed** — **not built yet.** The two DX7 voices in `voices.json` will fail to
  load until a Dexed LV2 build is added to `02-audio-stack` (same
  verify-on-hardware-then-codify path sfizz took). Its URI/param symbol in
  `_MODHOST_PLUGINS` (`https://asb2m10.github.io/dexed`, `sysex_file`) are
  unconfirmed until then.

## Open questions (from the design, still open)

- Exact mod-host audio-out port names — confirm with `jack_lsp -t` on the Pi
  before wiring Phase 2 audio.
- `is_ready` timeout per-engine vs global (Pianoteq starts slower than sfizz).
- Whether to add `pianoteq.service` (proprietary; only if/when installed).

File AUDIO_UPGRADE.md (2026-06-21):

# Upgrading Audio Quality — From SoundFonts to Professional Sound

## Context

This document is for a MIDI instrument built on a Raspberry Pi 4 with:
- PREEMPT_RT kernel (6.12.x, built from `rpi-6.12.y` with `bcm2711_rt_defconfig`)
- PCM5102 I2S DAC on ALSA device `hw:2`
- Audio pinned to CPU cores 2-3 with RT priority 80
- USB MIDI keyboard input
- Touchscreen UI (Pygame) on cores 0-1 for voice selection
- FluidSynth currently running as the audio engine via systemd service
- Communication between UI and audio engine via TCP

The SoundFont-based setup works but sounds amateur. This document covers upgrading to professional-quality sound.

## Architecture Change

Currently: FluidSynth is the only audio engine, controlled via TCP on port 9800.

New approach: Multiple audio engines, each specialized for what it does best. A manager process starts the right engine for the selected voice category.

```
Voice selected on touchscreen
    │
    ▼
Engine Manager (script/service)
    │
    ├── Piano/Sampled instruments → sfizz
    ├── Hammond Organ → setBfree
    ├── FM Synth / DX7 sounds → Dexed (via mod-host)
    ├── General MIDI / fallback → FluidSynth
    └── Physical modeling piano → Pianoteq (commercial)
```

**Critical design rule (unchanged):** The audio engine runs independently of the Python UI. If the UI crashes, audio continues. The architecture from CLAUDE.md still applies — the UI sends commands, it never manages the audio process directly.

## Engine 1: sfizz (Sampled Instruments)

sfizz is an SFZ-format sample player. SFZ is dramatically better than SoundFont — more velocity layers, round-robin, release samples, sympathetic resonance, legato transitions.

### Install

```bash
sudo apt-get install sfizz
```

If not available via apt:

```bash
sudo apt-get install build-essential cmake libsndfile1-dev libjack-jackd2-dev
git clone --recursive https://github.com/sfztools/sfizz.git
cd sfizz
mkdir build && cd build
cmake -DCMAKE_BUILD_TYPE=Release ..
make -j4
sudo make install
```

### Run with ALSA

```bash
chrt -f 80 taskset -c 2,3 sfizz_jack &
# or if using ALSA directly, sfizz can be loaded as an LV2 plugin via a host (see mod-host section)
```

sfizz is primarily an LV2 plugin or a JACK client. For direct ALSA usage without JACK, use it through mod-host (see below).

### Professional SFZ Libraries

#### Salamander Grand Piano (free, ~1.2GB)
The gold standard free piano. 16 velocity layers, release samples.

```bash
mkdir -p ~/instruments/piano
cd ~/instruments/piano
# Download from https://freepats.zenvoid.org/Piano/SalamanderGrandPiano/
# Or mirror: https://archive.org/details/SalamanderGrandPianoV3
# Look for the SFZ version, not the SF2 version
```

After downloading and extracting, you'll have a folder with WAV files and a `.sfz` file. The SFZ file is what you load into sfizz.

#### Piano in 162 (free, ~3GB)
Steinway Model D, 100+ velocity layers per note. Extremely realistic but large.

```bash
mkdir -p ~/instruments/piano
# Download from https://ivyaudio.com/Piano-in-162
```

#### Iowa Piano (free, ~500MB)
Dry Steinway recordings from the University of Iowa Electronic Music Studios. Good for adding your own effects.

```bash
mkdir -p ~/instruments/piano
# Download from http://theremin.music.uiowa.edu/MISpiano.html
# These are raw WAV samples — you'll need an SFZ mapping file
```

#### Other SFZ Libraries Worth Getting

- **Versilian Community Orchestra** — free orchestral instruments, very good quality
- **Karoryfer Samples** — free cello, guitars, choir
- **Virtual Playing Orchestra** — full orchestra SFZ set

Store all instruments in `~/instruments/` organized by category:

```
~/instruments/
├── piano/
│   ├── salamander/
│   │   ├── SalamanderGrandPianoV3.sfz
│   │   └── samples/
│   └── piano-in-162/
├── epiano/
├── organ/
├── synth/
└── strings/
```

## Engine 2: setBfree (Hammond B3 Organ)

setBfree physically models a Hammond B3 tonewheel organ. It computes the actual tonewheel sound generation, key click, drawbar settings, percussion, vibrato/chorus, and a Leslie speaker cabinet with rotating horn and drum. It sounds like a real B3 because it IS computing what a real B3 does.

### Install

```bash
sudo apt-get install setbfree
```

If not available:

```bash
sudo apt-get install build-essential libftgl-dev libglu1-mesa-dev libjack-jackd2-dev lv2-dev
git clone https://github.com/pantherb/setBfree.git
cd setBfree
make
sudo make install
```

### Run

```bash
chrt -f 80 taskset -c 2,3 setBfree -p hw:2
```

setBfree accepts MIDI CC messages for drawbar control, Leslie speed, vibrato, and percussion — map these to your foot controller's expression pedals and switches.

### Key MIDI Mappings for setBfree

- CC 1: Modulation (vibrato depth)
- CC 11: Expression
- CC 64: Sustain
- Drawbar CCs vary — check setBfree documentation
- Leslie speed: typically CC 1 or a dedicated CC

### Configuring setBfree

Create a config file at `~/.setBfreerc`:

```
# Audio output
jack.connect.output.left=system:playback_1
jack.connect.output.right=system:playback_2

# Default drawbar registration (Gospel organ sound)
osc.drawbar.upper=88 8000 000

# Leslie speaker
whirl.speed-preset=chorale
```

setBfree has extensive documentation for all its parameters.

## Engine 3: Dexed (DX7 FM Synthesis)

Dexed is a perfect recreation of the Yamaha DX7 FM synthesizer. It plays actual DX7 patches (SysEx format) — there are over 100,000 DX7 patches available online. Classic 80s electric pianos, bells, basses, pads, and the iconic FM sounds.

### Install as LV2 Plugin

```bash
sudo apt-get install dexed
```

If not available, build from source:

```bash
git clone https://github.com/asb2m10/dexed.git
cd dexed
# Build as LV2 plugin
# (build instructions vary — check the repo's README)
```

### DX7 Patch Libraries

DX7 patches come in SysEx (.syx) files, each containing 32 patches.

- **Download from**: https://yamahablackboxes.com/collection/yamaha-dx7-702-702-patches/
- **Also**: http://dxsysex.com/
- These are the actual patches from the 80s — the same sounds you've heard on thousands of records.

Store in `~/instruments/dx7/`:

```
~/instruments/dx7/
├── rom1a.syx    (original factory patches)
├── rom1b.syx
├── epiano-collection.syx
└── pads-and-strings.syx
```

### Famous DX7 Patches to Look For

- E.PIANO 1 (the iconic 80s electric piano — used on countless records)
- BASS 1 (the slap bass sound)
- TUBULAR BELLS
- LATELY BASS (used by Phil Collins, etc.)

## Engine 4: Pianoteq (Commercial, Optional)

Pianoteq is a physically modeled piano — no samples. It computes string vibrations, hammer mechanics, soundboard resonance, and duplex scale resonance in real time. It's what many touring professionals use.

### Why Consider It

- ~50MB install (no huge sample libraries)
- Every parameter is adjustable (hammer hardness, string length, soundboard material)
- Includes grand pianos, uprights, electric pianos (Rhodes, Wurlitzer), harpsichord, vibraphone, and more
- Runs well on Pi 4
- Stage license (~$100) or Standard (~$250) or Pro (~$450)

### Install

Pianoteq provides an ARM Linux build. Download from https://www.modartt.com/pianoteq and follow their Linux installation guide.

### Run

```bash
chrt -f 80 taskset -c 2,3 pianoteq --headless --midi-channel 1 --audio-device hw:2
```

### Trial Version

There's a free trial that plays every other note silently — enough to evaluate whether you want to buy it.

## Plugin Host: mod-host

mod-host lets you load LV2 plugins (sfizz, Dexed, effects) and connect them together. It runs headless and accepts commands via a socket — perfect for your architecture.

### Install

```bash
sudo apt-get install mod-host
```

If not available:

```bash
sudo apt-get install build-essential libjack-jackd2-dev liblilv-dev
git clone https://github.com/mod-audio/mod-host.git
cd mod-host
make
sudo make install
```

### Usage

Start mod-host:

```bash
chrt -f 80 taskset -c 2,3 mod-host -n -p 5555 &
```

Send commands via socket (from your Python UI or a script):

```bash
# Add a plugin (sfizz)
echo "add http://sfztools.github.io/sfizz 0" | nc localhost 5555

# Set a parameter (load an SFZ file)
echo "param_set 0 <sfz_file_param_id> '/home/synth/instruments/piano/salamander/SalamanderGrandPianoV3.sfz'" | nc localhost 5555

# Connect MIDI input
echo "connect midi_in effect_0:midi_in" | nc localhost 5555

# Connect audio output
echo "connect effect_0:out_left system:playback_1" | nc localhost 5555
echo "connect effect_0:out_right system:playback_2" | nc localhost 5555
```

### Why mod-host Is Powerful

You can chain plugins:

```
MIDI in → sfizz (piano) → reverb plugin → EQ plugin → audio out
```

Each plugin is added and connected via simple socket commands. Your Python UI can build and tear down signal chains on the fly.

## JACK Audio (Required for Most of These)

FluidSynth can run on raw ALSA, but setBfree, sfizz (standalone), and mod-host typically use JACK for audio routing. JACK is a low-latency audio server that sits between your applications and ALSA.

### Install

```bash
sudo apt-get install jackd2
```

### Configure for Low Latency

```bash
chrt -f 90 taskset -c 2,3 jackd -d alsa -d hw:2 -r 48000 -p 128 -n 2 &
```

This starts JACK on your DAC with the same buffer settings you used with FluidSynth. JACK's priority should be higher than the audio engines (90 vs 80) since it's the audio router.

### JACK as a Systemd Service

```ini
[Unit]
Description=JACK Audio Server
After=sound.target
Before=audio-engine.target

[Service]
Type=simple
User=synth
ExecStart=/usr/bin/chrt -f 90 /usr/bin/taskset -c 2,3 /usr/bin/jackd -d alsa -d hw:2 -r 48000 -p 128 -n 2
Restart=always
RestartSec=1

[Install]
WantedBy=multi-user.target
```

## Engine Manager

The engine manager replaces the single FluidSynth service. It starts the appropriate engine based on which voice category is selected.

### Concept

```bash
#!/bin/bash
# /usr/local/bin/engine-manager.sh
#
# Called by the Python UI when switching voice categories.
# Usage: engine-manager.sh <engine> [instrument-path]

ENGINE="$1"
INSTRUMENT="$2"

# Stop any running engine
killall -9 fluidsynth setBfree sfizz pianoteq 2>/dev/null
sleep 0.3

case "$ENGINE" in
    fluidsynth)
        chrt -f 80 taskset -c 2,3 fluidsynth \
            -a jack -m jack \
            -o synth.gain=2.0 \
            -s -i "$INSTRUMENT" &
        ;;
    sfizz)
        # Load via mod-host
        echo "remove 0" | nc -q 0 localhost 5555
        echo "add http://sfztools.github.io/sfizz 0" | nc -q 0 localhost 5555
        echo "param_set 0 sfz_file '$INSTRUMENT'" | nc -q 0 localhost 5555
        ;;
    setbfree)
        chrt -f 80 taskset -c 2,3 setBfree &
        ;;
    dexed)
        # Load via mod-host
        echo "remove 0" | nc -q 0 localhost 5555
        echo "add https://asb2m10.github.io/dexed 0" | nc -q 0 localhost 5555
        ;;
    pianoteq)
        chrt -f 80 taskset -c 2,3 pianoteq --headless \
            --midi-channel 1 &
        ;;
esac

# Reconnect MIDI after engine starts
sleep 1.5
/home/synth/midi-instrument/scripts/midi-connect.sh
```

### Integration with the Touchscreen UI

The Python UI's voice list would be organized by engine:

```
~/instruments/
├── voices.json        # manifest of all available voices
├── piano/
├── epiano/
├── organ/
└── dx7/
```

`voices.json`:

```json
[
    {
        "name": "Salamander Grand",
        "engine": "sfizz",
        "path": "/home/synth/instruments/piano/salamander/SalamanderGrandPianoV3.sfz",
        "category": "Piano"
    },
    {
        "name": "Hammond B3",
        "engine": "setbfree",
        "path": "",
        "category": "Organ"
    },
    {
        "name": "DX7 E.Piano",
        "engine": "dexed",
        "path": "/home/synth/instruments/dx7/rom1a.syx",
        "category": "Electric Piano"
    },
    {
        "name": "General MIDI",
        "engine": "fluidsynth",
        "path": "/home/synth/soundfonts/GeneralUser-GS.sf2",
        "category": "General MIDI"
    }
]
```

The UI reads this manifest, displays voices grouped by category, and calls the engine manager when a voice is selected. The engine manager stops the old engine, starts the new one, and reconnects MIDI.

### Communication Protocol

The current FluidSynth TCP approach (port 9800) is FluidSynth-specific. With multiple engines, you need a more general approach.

**Option A — Engine manager listens on a socket.** The Python UI sends commands like `load sfizz /path/to/file.sfz` to a socket. The engine manager translates these to engine-specific commands.

**Option B — The Python UI calls the engine manager script directly.** Simpler but tightly coupled.

**Option C — mod-host as the universal interface.** mod-host already has a socket interface. The Python UI always talks to mod-host. mod-host loads whatever plugin is needed. This is the cleanest because mod-host handles all the JACK routing, plugin lifecycle, and parameter control through one consistent API.

**Recommendation: Option C with mod-host as the permanent service.** JACK and mod-host run as always-on services. The Python UI sends socket commands to mod-host to load/unload plugins. setBfree and Pianoteq would run as standalone JACK clients managed by a simple wrapper.

## Recommended Implementation Order

1. **Install JACK** and verify audio works through it with your DAC
2. **Install sfizz** and load Salamander Grand Piano — this alone will be a dramatic upgrade
3. **Install setBfree** for organ — test it standalone
4. **Install mod-host** and learn to load plugins via its socket interface
5. **Update the Python UI** to read voices.json and call the engine manager
6. **Install Dexed** for FM sounds
7. **Evaluate Pianoteq** trial if you want the best possible piano

## Things That Must Not Change

- Audio engines run on cores 2-3 with RT priority
- JACK runs at priority 90, engines at priority 80
- The Python UI runs on cores 0-1 and never manages audio processes directly
- MIDI auto-connection runs after every engine switch
- The DAC is ALSA device hw:2
- All engine processes must handle being killed cleanly (SIGTERM then SIGKILL)

## Effects

Once you have mod-host running, you can add effects plugins to any engine:

**Essential LV2 effects plugins:**

```bash
sudo apt-get install calf-plugins        # reverb, EQ, compressor, delay
sudo apt-get install lsp-plugins-lv2     # excellent parametric EQ, compressor
sudo apt-get install guitarix-lv2        # amp sims, cabinet sims
sudo apt-get install zam-plugins         # compressor, EQ, delay
sudo apt-get install dragonfly-reverb    # excellent algorithmic reverbs
```

A typical signal chain:

```
MIDI → Piano plugin → Parametric EQ → Plate Reverb → DAC
```

All controlled via mod-host socket commands. Your Python UI could have an effects section where you add/remove/configure effects in the chain.

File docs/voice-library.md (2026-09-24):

# Voice library — everything through mod-host

How the instrument library is described, validated, and (progressively) moved so
that every voice is an LV2 plugin in one mod-host process. Companion to
[`engine-architecture.md`](engine-architecture.md), which owns the JACK graph and
core allocation.

## Why consolidate on mod-host

Three engine mechanisms exist today — fluidsynth (systemd unit + TCP 9800),
setBfree (systemd unit, no control channel), mod-host (LV2 over a socket). Three
lifecycles, three failure modes, three RT configurations. Two capabilities are
hostage to that split:

- **Effects only work under a mod-host instrument.** `EngineManager.effects_available()`
  is literally `_is_active("modhost")`, so the Hammond and the GM piano can never
  have reverb.
- **`set_gain` only reaches fluidsynth.** No master level, and no way to
  level-match voices against each other.

And switching costs a process cold start: `systemctl start` → JACK port
registration → an LV2 world scan (`ModHostEngine._load_plugin_with_retry` waits
up to 10s for it) or a soundfont read.

**The payoff isn't the host, it's residency.** Once every instrument is an LV2
plugin in one process, plugins can stay *instantiated* at instances 0–9 and a
switch becomes bypass + re-patch — no process start, no instantiate, no world
scan. That is where "switching is faster" actually comes from; moving engines
into mod-host one-for-one only buys uniformity.

**The honest cost:** mod-host processes every instance in one thread, so all
resident non-bypassed plugins share a single period deadline, and one bad plugin
takes down every voice rather than one. That ceiling is lower than N processes
across cores — but per `engine-architecture.md`, instrument → effects is a serial
data dependency anyway, so the parallelism being given up was never real.

## Voice schema

A voice is data. Adding an LV2 instrument is a `voices.json` edit and nothing
else — no engine class, no table in the code:

```json
{
  "name": "Rhodes EP",
  "engine": "modhost",
  "uri": "http://drobilla.net/plugins/mda/EPiano",
  "category": "Electric Piano",
  "resident": true
}
```

| field | meaning |
|---|---|
| `engine` | `modhost` for any LV2 instrument. `sfizz`/`dexed` are legacy aliases that carry their URI in `lv2.PLUGIN_SPECS`; `fluidsynth`/`pianoteq` are the remaining process engines |
| `uri` | LV2 plugin URI. Required for `modhost` |
| `path` | instrument file (SFZ/SF2/.syx), if the plugin takes one |
| `file_property` | the LV2 **patch property** `path` is set through. Patch properties are atom-based and only reachable via mod-host `patch_set` — `param_set` silently no-ops on them, which is what made sfizz load-but-stay-silent |
| `preset` | LV2 preset URI applied after instantiation |
| `params` | control-port symbol → value, applied *after* `preset` so a voice can start from a stock preset and override a few controls |
| `gain_trim_db` | per-voice output trim, so switching from a sampled piano to a B3 doesn't jump in level. Consumed by the master gain stage (Phase D) |
| `resident` | keep this plugin instantiated rather than loading on demand — the basis of instant switching. Only for plugins cheap in RAM; **not** large sample libraries |

`preset` + `params` are the library multiplier — one plugin backing several
entries. Note which lever applies: `params` needs the plugin to expose control
ports, and some don't. b_synth has **none** (setBfree takes drawbars, Leslie and
percussion over MIDI CC), so multiple organ registrations have to go through
`preset` and its `state#interface`, not `params`.

## SoundFont voices: one file is a library

A `.sf2` holds up to 128 programs per bank. Naming only the *file* collapsed all
of `fluid-soundfont-gm` — already installed — into a single "General MIDI" entry,
leaving its Rhodes, Wurlitzer, drawbar organ and synth brass unreachable. `bank`
and `program` fix that:

```json
{ "name": "Wurlitzer", "engine": "fluidsynth",
  "path": "/home/synth/soundfonts/default.sf2",
  "category": "Electric Piano", "program": 5 }
```

`program: -1` (the default) means "don't select", preserving old behaviour.
Switching between two voices from the same font is a `select` on the already
resident font — no reload, no restart.

`FluidSynthController.current_sfont_id()` exists because the engine boots with
the default font as sfont **1**, so a font loaded later is not 1; selecting a
program on 1 would quietly play an instrument from the wrong font. That was
latent before `program` existed and only became reachable with it.

These voices are process-engine voices, so they run fluidsynth on core 2
alongside mod-host — the pairing the pi4 xrun note warns about. They still feed
the master chain and the effects rack like everything else, which is what makes
a plain GM Rhodes usable: put a chorus and a reverb after it.

## Validation

The manifest ships in the image and can outrun what's installed. It did: it
referenced SFZ libraries no image stage creates and a Dexed plugin that was never
built, so **four of six voices failed only when tapped**.

`clients/voice.py validate()` now resolves each voice against the filesystem and
against `lv2ls`, returning a reason string (`"file missing"`, `"plugin not
installed"`, `"no file property for this plugin"`, `"no plugin URI"`, `"unknown
engine"`). Three consumers:

- **The UI** greys the row and shows the reason as its subtitle instead of
  logging it, and won't let it be tapped (`ui/components/voice_list.py`).
- **Boot** falls back to the first *available* voice when the saved/default voice
  isn't usable on this unit — the unit plays on boot rather than going silent.
- **`python3 -m synth_ui.tools.verify_voices`** validates the whole manifest and
  exits non-zero if anything is unusable, so a build or deploy can gate on it.

`LV2World.has()` is deliberately optimistic when `lv2ls` can't be run at all (a
dev machine): a missing tool must not grey out the entire library. Only a world
that was successfully enumerated can rule a URI out.

### Verify on hardware, then codify

`verify_voices --inspect <uri>` prints a plugin's control symbols and patch
properties via `lv2info` — exactly what `params` and `file_property` need. That's
how an unverified URI, or Dexed's still-unknown `.syx` property, gets filled in
without guessing. `lilv-utils` is in `00-packages` for this.

## Plugin sources, cheapest first

**Already in the image** (`mda-lv2`, `calf-plugins` were added for effects, but
both ship instruments): mda EPiano / Piano / DX10 / JX10 / Organ, Calf Organ,
Calf Monosynth. Tiny CPU, instant load, no instrument file. These are in
`voices.json` now — **their URIs are inferred and unverified**; run
`verify_voices` on the board, and anything wrong greys out rather than breaking.

**Apt.** `setbfree` ships the `b_synth` LV2 (Leslie included) at
`/usr/lib/lv2/b_synth` — that *is* the Hammond now, and the package must stay
installed even though its standalone binary is no longer run. `amsynth` is light
with a large preset bank if more analog synth voices are wanted.

**Needs a build** (`02-audio-stack`). Dexed, only if DX7 specifically matters —
mda DX10 plus amsynth cover much of that ground for free.

**Not movable:** Pianoteq, if it's ever bought — no LV2 on Linux ARM as far as we
know. `ProcessEngine` stays alive for exactly that case.

## The master chain

Everything — every voice, and the whole effects rack — now feeds a permanent tail
in mod-host before reaching the DAC:

```
instrument -> [ effects rack ] -> [ MASTER: trim -> limiter ] -> system:playback
```

It exists for two reasons. **Level matching:** each voice carries a measured
`gain_trim_db` applied here, summed with the user's volume, so switching from a
sampled piano to a B3 doesn't jump. **Peak safety:** a limiter last in the path
means nothing clips while levels are being dialled in.

Leaving it running costs little, and the reason matters: what causes dropouts
here is per-period *variance*, not average load. A gain stage and a limiter cost
the same work every period — no disk reads, no allocation, no worker threads —
which makes them the best-behaved things in the graph, unlike a sampler whose
cost spikes on first-touch sample reads. Keep it to gain/limit/EQ; a reverb
belongs in the per-rig rack.

**Automatic leveling was rejected.** A compressor or AGC on the master would even
the instruments out, but it would flatten playing dynamics too — fixing the
switching problem by breaking expression. Fixed per-voice offsets instead.

Two consequences:

- **mod-host is always-on again** (enabled at boot, `PartOf=jack.service`). It
  can't be tied to whether a mod-host *instrument* is active when it hosts the
  output path for every voice. This reverses the pi4-era on-demand lifecycle;
  see the caveat below.
- **Effects work under every voice.** `effects_available()` is now
  unconditionally true — the Hammond and the GM piano can have reverb, which the
  old gate made impossible.

### Calibration

`python3 -m synth_ui.tools.calibrate_levels --midi <file>` plays one fixed
passage into every voice, records the master output, measures **EBU R128
integrated loudness** (not peak — two instruments can peak identically and
differ hugely in perceived level), and writes `gain_trim_db` back into the
manifest. `--dry-run` measures without writing.

It's a starting point, not the last word: measured loudness and "sits right when
I play it" differ, and a voice matched at medium touch can still diverge when you
dig in — that's velocity response, a separate axis from gain. The by-ear nudge on
top is what a rig's `trim_db` stores.

## Residency — why switching is fast

`clients/slots.py` (`InstrumentSlots`) keeps instrument plugins **instantiated**.
A switch between two loaded voices is a bypass flip plus a JACK re-patch; nothing
is instantiated, no LV2 world is scanned, no sample library is re-read. That is
the payoff the whole consolidation was for — putting instruments in one host was
the means, not the end.

Two kinds of voice, because RAM is finite:

- `resident: true` — small synths (mda, Calf). Each keeps its own slot in `0-8`.
  When they outnumber the slots, the least recently used is evicted: bounded
  memory, nothing to configure.
- `resident: false` — large sample libraries. Several resident would blow the RAM
  budget, so they share the scratch slot `9` and pay the load cost on switch. The
  old behaviour, now confined to the voices that actually need it.

A slot is matched on plugin URI **and** instrument file: two sfizz voices are one
plugin but different pianos, and treating them as interchangeable would leave you
playing the wrong one.

**The correctness consequence, which is easy to miss.** Switching used to unload
the outgoing instrument, and jackd dropped its edges automatically because the
ports vanished. Resident instruments keep their ports, so nothing drops them —
without an explicit disconnect the previous voice would go on receiving the
keyboard and go on feeding the sink, i.e. two instruments sounding at once.
`EngineManager._unwire` does that, still connect-before-disconnect so there's no
silent gap, and it leaves alone any port shared with the incoming engine.

**Warming a set.** Entering a set pre-instantiates its rigs' instruments
(`EngineManager.warm`, called from `app._start_set`) so every switch *within* a
song is a bypass flip and a re-patch. It happens after the first rig is loaded —
sound first, and it leaves the rig about to be played as most-recently-used so
it can't be the one evicted. Non-resident voices are skipped: they share the one
scratch slot, so warming two sample libraries would evict each in turn.

Measured on the CM5, mod-host CPU over 8s windows with nothing playing:

| warmed, bypassed | 0 | 1 | 2 | 4 | 8 |
|---|---|---|---|---|---|
| mod-host CPU | 0.2% | 0.5% | 0.4% | 0.6% | 1.7% |

Eight warmed instruments cost ~1.5% of one core, no xruns. The 1/2/4 figures are
inside the noise (~±0.2%) and don't order correctly — read it as roughly 0.2%
each, too small to measure singly. Warming a whole set is not worth rationing.

**Bypass does not skip processing.** Measured the same way, 8 bypassed and 8
un-bypassed cost the same (1.7% vs 1.6%). mod-host's source says why: its bypass
branch zeroes the buffers and then calls `lilv_instance_run()` anyway, with the
comment *"Run the plugin with zero buffer to avoid 'pause behavior' in delay
plugins"*. A bypassed reverb has to keep consuming silence or its tail freezes.
So bypass buys silence, not CPU — this resolves the open question below.

**Bypass isn't trusted for silence.** An inactive instrument is bypassed *and*
has its MIDI disconnected, so it gets no notes by either route. That belt-and-
braces turns out to be the right call for a second reason: bypass is not a skip
(above), so a bypassed instrument still runs every period — what stops it making
sound is that mod-host silences its output buffers, and what stops it having
anything to say is the missing MIDI connection. Resident voices are therefore
not free at idle, but at ~0.2% of a core each the eviction bound is more than
enough to keep it in check.

## Rigs

A **rig** is instrument + effects chain + level, saved and switchable as one
unit. Note the naming: "preset" already means a soundfont's bank/program here
(`synth_client.Preset`, the preset screen), so the larger thing is a rig.

**A rig belongs to exactly one set, and is stored inside it** (`clients/set.py`,
`~/.synth-sets.json`, written atomically — deliberately separate from
`voices.json`, which is a read-only catalog shipped in the image). A set is one
song's worth of rigs: you enter it and see those four pads, and the footswitch
walks those four rather than the whole store. `RigsScreen._step` iterates
whatever list the screen holds, so scoping the list *is* the mechanism.

Containment rather than reference — sets hold rigs, they don't point at them.
Copying a rig into a second song costs a config file's worth of bytes, and buys
more than it costs: a shared rig would change under you between songs, and
per-song copies can't. It also removes every cross-reference bug — no dangling
ids, no renaming a rig out from under what points at it. Removing a rig from a
set *is* deleting it.

Both sets and rigs carry a uuid and their names are metadata, so two songs can
each hold a rig called "Rhodes" and renaming one can't turn it into a different
rig. `~/.synth-state` records the active set and rig by id for the same reason.

A board that predates sets is migrated on first load: its `~/.synth-rigs.json`
becomes one set, in order, and the old file is left in place as the backup.

**A rig carries the instrument's patch too** (`Rig.voice_params`, control symbol
→ value). The catalog is read-only, shipped in the image and overwritten by
`deploy.sh`, and one entry has to serve every rig built on it — so the values
that make a sound (this pad's slow attack, that lead's cutoff) belong to the rig,
not the voice. They are layered over the catalog entry's `params` when the rig
loads, and only the *difference* from the catalog is stored, so a corrected value
in a shipped voice still reaches the rigs built on it. The UI edits them live
through the same screen an effect gets, because an LV2 instrument is a plugin
with control ports like any other; tapping the instrument block opens it, and
swapping the instrument moved to that screen's header.

That makes one plugin backing several *rigs* as ordinary as one plugin backing
several voices, which is why `InstrumentSlots` remembers what it last wrote to
each slot and reconciles on acquire (`_reconcile`). Matching a loaded plugin on
URI alone — which is all `_find` did — handed the next voice the previous one's
settings untouched: the right name, the wrong sound, and nothing in the log.
Controls the incoming voice doesn't mention go back to the plugin's default
rather than being left alone, or a cutoff dialled down in one rig would follow
the instrument into every other rig on it. Reading those defaults means running
`lv2info`, so it happens only when something actually has to be undone, and is
cached per plugin.

**Loading a rig is a diff, not a rebuild.** The obvious implementation — tear the
rack down, build the new one — makes every rig change pay to instantiate every
plugin in it, which is exactly the cost this architecture exists to avoid.
`rig.plan()` compares the target chain against what's loaded and returns the
minimum change: effects common to both rigs keep their instance and are
re-ordered rather than reloaded, so two rigs sharing a reverb switch without
touching it. Duplicate URIs are matched positionally, so a rig with two delays
keeps both.

Instance numbering across the whole host: instruments `0-9`, effects `10-89`,
master chain `90+`.

### The UI is rig-first

Rigs, not voices, are what you pick — a rig is a whole sound, which is what you
reach for when playing. The screen hierarchy moved accordingly:

| screen | role |
|---|---|
| `screens/sets.py` (**home**) | the sets; tap to enter. Actions: New / Audio |
| `screens/rigs.py` | one set's rigs; tap to load. Actions: Back / New / Edit |
| `screens/voice_picker.py` | the instrument catalog, reached via **New**. Picking a voice creates a rig in the active set. Owns USB import, since that changes the catalog |
| `screens/effects.py` | the active rig's chain. Leaving the screen writes it back to the rig |
| `screens/text_entry.py` | naming — and, via `on_delete`, the only route to deleting a rig or a set |
| `screens/settings.py` | brightness, MIDI-in status and reconnect, network address, shutdown. Reached by the cog |

`screens/home.py` is gone — `VoicePickerScreen` is what it became. The settings
**cog** owns the far-right header slot on every screen that has one, so it is
always under the same thumb; every other action shifts left of it. It is absent
from the modal screens — naming something, or picking from a catalogue — where
that slot belongs to Done and a cog would discard what you had typed.

**There is no audio device picker.** `scripts/start-jack.sh` already resolves the
card by name (saved choice → HiFiBerry → first available → jackd's dummy
backend), which is how this board has always chosen it: nothing was ever saved
to `~/.synth-audio-device` and JACK opens `hw:sndrpihifiberry` on its own. The
only other card is the carrier board's onboard USB codec, whose jack is sealed
inside the enclosure — so the picker's sole power was to move audio somewhere
worse. A hand-written `~/.synth-audio-device` is still honoured.

**Entering a set you're not already in makes it active and loads its first
usable rig**; re-entering the set you're in changes nothing, which is what makes
coming back from editing a chain safe; and returning to the sets screen never
changes what's playing. So the active rig can legitimately belong to a set that
isn't on screen, and `RigsScreen.set_rigs` therefore does *not* clear it —
browsing is not switching. Only `rig_removed` clears it, on an actual deletion.

Rules that live in `SongSet`/`SetLibrary` rather than in the screens, so they're
testable without pygame: rigs are named after the voice they start from with numeric
suffixes on collision (two rigs on one instrument is normal — dry vs wet); a
fresh card with no sets bootstraps one holding a `DEFAULT_VOICE` rig so the unit
boots into something playable; a rig whose voice has left the catalog is greyed
with the reason rather than loading to silence.

**Naming is automatic but no longer permanent.** A new rig still takes its
instrument's name; the touchscreen keyboard that was missing exists now
(`screens/text_entry.py`), so renaming is reachable by long-pressing a tile —
and since the name is metadata rather than identity, a rename is a plain
assignment that can't collide with anything.

**A rig doesn't capture a soundfont program.** Picking a GM voice still drills
into the preset screen, but the chosen bank/program isn't stored in the rig —
only the voice is.

## Phases

- **A — library + validation. Done.** Voice schema, `clients/lv2.py`, validation
  in UI + boot + CLI, URI-driven `ModHostEngine` (`engine: "modhost"` needs no
  code), `preset_load` on `ModHostClient`, seven new voices.
- **D — master chain + level + rigs. Done.** `MasterChain`, routing through it,
  universal volume, `calibrate_levels`, `Rig`/`plan`/`RigLibrary` +
  `EngineManager.load_rig`, and the rig-first UI (rig list, voice picker,
  effects writing back to the rig). Gaps: no rename (needs a touch keyboard),
  and a rig doesn't store a soundfont program.
- **B — residency. Done.** See below.
- **C — Hammond to `b_synth`**, retire `setbfree.service`.
- **C — Hammond into mod-host. Done.** `b_synth` (setBfree's own DSP) is the
  Hammond; `setbfree.service`, its sudoers entry and `SetBfreeEngine` are gone.
  **The `setbfree` apt package stays** — Debian ships the LV2 bundle at
  `/usr/lib/lv2/b_synth` (no `.lv2` suffix, which is why a path-based build guard
  missed it and built a redundant copy). Plugin builds are now guarded on the URI
  via `lv2ls`, not on a guessed path.

  b_synth exposes **no control ports** — drawbars, Leslie and percussion are MIDI
  CC. So registrations can't live in a voice's `params`. It does implement
  `state#interface`, so the route to Gospel/Rock/Jazz variants is mod-host
  `preset_save` on a live-adjusted organ, recalled through the existing
  `Voice.preset` → `preset_load`. Deferred until the engine migration is done.
- **E — the last process engine.** Both are now the same problem: get an
  LV2 plugin at the head of the chain so nothing needs its own service.
  `02-audio-stack` builds **b_synth** (setBfree's own DSP as a plugin — the same
  tonewheels, key click, percussion and Leslie, which is why it beats Calf Organ
  or mda Combo for a B3) and **Fluida** (a SoundFont player). Both entries exist
  in `lv2.PLUGIN_SPECS`; Fluida's `file_property` is the one unknown, and
  `verify_voices --inspect` now answers it directly. Migrating the 20 GM voices
  is then a change of `engine`/`uri` per entry — `bank`/`program` carry over
  unchanged. **Fallback if Fluida doesn't expose the soundfont headlessly:**
  convert the .sf2 to SFZ and use sfizz, which is already built and proven; it
  costs disk and load time but adds no new plugin at all.
- **E (old framing — superseded by C/E above).** Either Calf Fluidsynth in mod-host (retiring `fluidsynth-engine`
  and `synth_client.py`) or drop GM for a curated library. Open question: whether
  GM program-change browsing (`list_presets`/`select_preset`) is worth
  preserving.
- **F — budget.** Measure with mod-host's `cpu_load` and the JACK xrun counter,
  one resident plugin at a time, and codify the ceiling.

## Consequences to handle

- **mod-host is always-on again — verify the xrun cost on the CM5.** Its
  on-demand lifecycle existed because two RT clients contended for core 2 on the
  *pi4* (~180 xruns/min). That measurement predates this board. The window where
  it can still bite is exactly "a process engine is active alongside mod-host" —
  i.e. selecting the Hammond or the GM voice. Check
  `journalctl -u jack | grep -c XRun` with each of those loaded and playing. It
  stops mattering once both move into mod-host (phases C and E).
- **Single point of failure.** One process owns every voice. `Restart=on-failure`
  is set, but `EngineManager` has no rebuild path: after a crash it still
  believes its plugins are loaded. Phase B needs a `_rebuild()` that replays
  resident plugins, params, and wiring on socket reconnect.
- **`DEFAULT_VOICE` is `"General MIDI"`** and depends on fluidsynth existing. It
  has to move to a guaranteed-present mod-host voice before Phase E, or
  boot-plays-immediately breaks. (The available-voice fallback added in Phase A
  covers this in the interim.)
- **The xrun numbers in `engine-architecture.md` are pi4 measurements** (~180 →
  ~65 xruns/min moving mod-host to cores 2,3; the `chrt` priority inversion).
  The reasoning carries over to the CM5, the numbers do not — re-measure before
  treating any of them as the budget.

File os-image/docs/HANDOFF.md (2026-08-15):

# pi-synth-os — design handoff (historical)

> **Status: historical.** This is the original design handoff that seeded the
> image build. It has since been implemented — see [`../README.md`](../README.md)
> and [`../stage-pi-synth/`](../stage-pi-synth/). Where the implementation
> deliberately diverged from this document:
>
> - **In-repo, not a separate `pi-synth-os/` repo.** The image build lives here
>   under `os-image/`; the app source is referenced directly (mounted into the
>   build), so no cross-repo vendoring is needed.
> - **Shell-based graph patching, not `JACK-Client` bindings.** The shipped code
>   patches JACK via `scripts/engine-manager.sh` + `scripts/midi-connect.sh`
>   (`jack_lsp`/`jack_connect`) and a mod-host TCP socket — there is no
>   `python-jack` dependency and no venv (only runtime dep is pygame).
> - **RT kernel is harvested from a working RT Pi** — raw artifacts
>   (`kernel8.img` + `/lib/modules/<KVER>`) baked in from `os-image/kernel/`, not
>   a `.deb` and not built in CI (Debian's `linux-image-rt-arm64` doesn't work on
>   Raspberry Pi OS, which uses a Pi-specific kernel + boot path).
> - Stages are `00-base-packages` … `06-system-tuning` (see the README table);
>   Plymouth is deferred as an optional phase-2 stage.
> - **pi-gen is fetched on demand by `build.sh` (pinned commit), not a git
>   submodule.** `os-image/pi-gen/` is gitignored; it's treated as a build tool,
>   not vendored into the repo.
>
> The architecture rationale below (engine model, no-Python-in-note-path, pi-gen
> choice, RT tuning) remains accurate and is why the current design looks as it
> does.

---

Context for picking this up in a fresh conversation. Source project:
https://github.com/ianbakst/pi-synth — a Raspberry Pi hardware synth with
multiple swappable instrument engines (FluidSynth, sfizz, setBfree, Dexed,
Pianoteq). This doc captures the architecture decided so far and the
build-out of a custom `pi-gen` OS image for it. Nothing here has been
pushed to git yet — it's all local scaffold under `pi-synth-os/`.

## Goal, in one sentence

Instruments must be hot-swappable at runtime even though they run on
fundamentally different engines, with the lowest achievable MIDI-to-sound
latency, on a Raspberry Pi OS image trimmed to exactly what this appliance
needs.

## Key architecture decisions (in order arrived at)

1. **Common `Engine` interface, one `EngineManager` behind it.**
   Every engine (FluidSynth, sfizz, setBfree, Dexed, Pianoteq) implements
   the same lifecycle interface (`start`, `stop`, `is_ready`, plus a MIDI
   port identifier) so the UI never needs to know which engine is active.
   `ProcessEngine` (FluidSynth, setBfree, Pianoteq) manages a subprocess;
   `ModHostEngine` (sfizz, Dexed) talks to mod-host's persistent socket
   instead of spawning/killing a process per switch.

2. **No Python in the note path — data plane vs. control plane split.**
   This was a deliberate course-correction: an earlier draft had Python
   objects calling `send_note`. Rejected. Final design: MIDI keyboard →
   `a2jmidid` (ALSA→JACK bridge) → JACK graph → active engine's JACK MIDI
   input → JACK audio out → DAC. Notes and samples never touch Python.
   Python's only job is **graph patching**: on an instrument switch, the
   `EngineManager` calls `jack.connect()`/`jack.disconnect()` (via the
   `JACK-Client` Python bindings, calling into libjack directly — this was
   explicitly chosen over shelling out to `jack_connect`/`aconnect`
   binaries, for lower per-switch overhead) to rewire which engine the
   keyboard's MIDI output is connected to. Connect-new-before-disconnect-
   old ordering avoids a silent gap. `mod-host`-hosted engines (sfizz,
   Dexed) are cheaper still to swap — it's a `remove`/`add` on mod-host's
   own always-running JACK client, not a process restart at all.

3. **Language choice for the UI: stick with Python; a compiled UI
   language would not reduce audio latency**, because the control plane
   was already taken out of the realtime path by decision #2. A compiled
   language (e.g. Rust) *would* help UI frame smoothness, memory/boot
   footprint, and robustness under load — legitimate reasons, just not a
   latency-on-the-note-path reason. Left as an open decision for the user
   to make on those grounds if they want to.

4. **Custom Plymouth boot splash**, replacing the rainbow gradient
   (`disable_splash=1` in `config.txt`, which can only blank it, not
   theme it — that stage is GPU firmware, pre-Linux) and the systemd
   status text (`quiet splash logo.nologo vt.global_cursor_default=0
   loglevel=3` in `cmdline.txt`). Plymouth theme is a `script`-module
   theme (supports static logo or frame-by-frame animation) requiring
   `auto_initramfs=1` in `config.txt` so Plymouth loads early enough.

5. **Custom OS image via `pi-gen`, not a hand-trimmed Lite install or a
   Buildroot/Yocto rebuild.** Reasoning: Buildroot/Yocto is overkill effort
   for a hobby appliance where disk size barely matters; hand-trimming
   Lite after the fact is not reproducible. `pi-gen`'s stage system lets a
   single custom stage (`stage-pi-synth/`) fully replace upstream's
   desktop-oriented stages 3–5, via the `STAGE_LIST` variable in `config`.

6. **Realtime performance tuning, once "lean" was clarified to mean
   *performance*, not disk size:**
   - `PREEMPT_RT` kernel — **user has already confirmed a working RT
     kernel for their specific board and installed it themselves**, so
     the build script for this is intentionally left as an explicit
     either/or fill-in (apt package vs. self-built `.deb`) rather than
     guessed at.
   - `isolcpus=3 nohz_full=3 rcu_nocbs=3` — dedicate one core to
     JACK/engines, keep the Python control plane on the other cores via
     `CPUAffinity=` in its systemd unit (inverse of JACK's).
   - `SCHED_FIFO` priority for JACK (`jackd -R -P89`), `rtprio`/`memlock`
     grants via `/etc/security/limits.d/`.
   - IRQ steering for the audio interface onto the isolated core, via a
     boot-time oneshot systemd service (can't be done at image-build
     time — depends on runtime hardware enumeration).
   - CPU governor `performance`, not `ondemand`.
   - No swap, ever (`dphys-swapfile` purged).
   - Disable Wi-Fi/Bluetooth/HDMI/unused services entirely at the image
     level (`avahi-daemon`, `triggerhappy`, `ModemManager`, `cron`, etc.)
     — framed as removing sources of scheduling jitter, not just saving
     RAM.
   - `journald` set to volatile/RAM-only storage.
   - Ceiling acknowledged as real, not just under-tuned: USB polling
     interval (~1ms) and Pi ARM/GPU shared memory bandwidth are hardware
     floors; an I2S DAC HAT would remove the USB round-trip entirely and
     was flagged as the biggest remaining win if/when the user wants a
     hardware change. Realistic tuned target: 32–64 sample buffers at
     48kHz (~1.5–2.5ms round trip) stable under sustained load.
   - Validation method: `cyclictest -m -Sp99 -i200 -l100000` for
     scheduling floor; watching JACK's own xrun counter over a 10+ minute
     sustained-switching session, not just an idle test, to confirm the
     tuning holds under real load rather than just looking good at rest.

## `pi-gen` mechanics (for whoever picks this up)

- Stages are numbered directories; each contains numbered subdirectories;
  each of those runs numbered scripts (`00-packages` = apt list processed
  automatically, `NN-run.sh` = anything else).
- `NN-run.sh` files execute **on the host**, operating against
  `${ROOTFS_DIR}`. Anything that needs to run *inside* the target
  filesystem goes in an `on_chroot << 'EOF' ... EOF` block within that
  script.
- `STAGE_LIST` in the top-level `config` file overrides the default
  numeric stage order — this repo uses `stage0 stage1 stage2
  stage-pi-synth`, i.e. stages 3–5 (desktop, recommended software) are
  never referenced, not merely skipped.
- Build via `sudo ./pi-gen/build.sh` (native) or `./pi-gen/build-docker.sh`
  (recommended for reproducibility — same result regardless of host
  machine, though it still needs kernel-level loop devices/binfmt on the
  host, so a Linux host or VM either way).
- `pi-gen` is a git submodule pinned to a specific `bookworm`-branch
  commit/tag deliberately, not tracked at `master`, so a `git pull` here
  never silently changes the base OS between builds.
- Iterating: touch a `SKIP` file in a stage directory to not rebuild it,
  `SKIP_IMAGES` to suppress image export for a stage that has one, to
  avoid a 45+ minute full rebuild per small edit.

## Repo layout, current state

```
pi-synth-os/
├── .gitignore
├── .gitmodules              # pi-gen submodule, pinned to bookworm branch
├── config                   # STAGE_LIST etc.
├── kernel-build/            # scaffolded, empty -- for the user's own
│                            # RT kernel cross-compile tooling if they
│                            # want it version-controlled here too
├── docs/
│   └── HANDOFF.md           # this file
└── stage-pi-synth/
    ├── 00-base-packages/
    │   ├── 00-packages      # python3, build-essential, git, etc.
    │   └── 00-run.sh        # pip installs JACK-Client
    ├── 01-realtime-kernel/
    │   ├── 00-run.sh        # RT kernel install (left as explicit
    │   │                    # either/or fill-in per user's own setup),
    │   │                    # config.txt + cmdline.txt edits for
    │   │                    # isolcpus/quiet-boot/auto_initramfs
    │   └── files/           # empty, drop a prebuilt kernel .deb here
    │                        # if using the "self-built" method
    ├── 02-audio-stack/
    │   ├── 00-packages      # jackd2, a2jmidid, fluidsynth, sfizz-lv2, etc.
    │   ├── 00-run.sh        # builds mod-host from source, installs
    │   │                    # setbfree, enables jack/mod-host services
    │   └── files/
    │       ├── jack.service      # CPUAffinity=3, SCHED_FIFO via -P89
    │       └── mod-host.service  # depends on jack.service
    ├── 03-plymouth-splash/
    │   ├── 00-packages      # plymouth, plymouth-themes, initramfs-tools
    │   ├── 01-run.sh        # installs theme, plymouth-set-default-theme -R
    │   └── files/pi-synth/
    │       ├── pi-synth.plymouth
    │       ├── pi-synth.script   # static logo by default; commented-out
    │       │                    # frame-loop version for animation
    │       └── README.md    # reminder to drop in logo.png/frameNN.png
    └── 04-pi-synth-app/
        └── files/
            └── pi-synth.service  # the control plane's own unit --
                                  # CPUAffinity=0,1,2 Nice=5, deliberately
                                  # kept OFF the isolated core

```

## Not yet done — pick up here

- **`04-pi-synth-app/00-run.sh`** — not written yet. Needs to: vendor the
  actual `pi-synth` repo code (controller + UI) into the image via
  `files/`, `pip install -r requirements.txt` into a venv at
  `/opt/pi-synth/.venv`, install `pi-synth.service` (already written) and
  enable it. **This requires the user's actual `controller/backend.py`,
  `fluidsynth.py`, etc. source** — earlier attempts to fetch these from
  GitHub directly were blocked by the fetch tool (only URLs already
  surfaced via search or prior fetch are fetchable); ask the user to
  paste file contents or provide a fetchable link if writing real engine
  classes rather than the illustrative sketches used so far in
  conversation.
- **`05-system-tuning/`** — directory not yet created in this session's
  file scaffold (it was written out in chat as code blocks in the
  previous turn, but the *files* on disk under `stage-pi-synth/` haven't
  been created yet). Needs: `00-run.sh`, `files/audio-rt.conf` (rtprio/
  memlock limits), `files/pin-audio-irq.sh` + `.service` (boot-time IRQ
  steering oneshot). Content for all of these was drafted in chat and
  just needs to be written to disk in the same style as the other stages.
- **`EXPORT_IMAGE`** marker file — needs to be added to
  `stage-pi-synth/` (or whichever is the final stage) so `pi-gen`
  actually produces a bootable image from it.
- **Top-level `README.md`** — not yet written. Should cover: clone with
  `--recursive`, `sudo ./pi-gen/build-docker.sh`, where the image lands
  (`pi-gen/deploy/`), and the `SKIP`/`SKIP_IMAGES` iteration workflow.
- **Read-only root filesystem / overlay** — discussed as a good idea for
  power-cut resilience during the earlier "reduce OS size" tangent, but
  no concrete implementation was designed or written. Would need its own
  stage or an addition to `05-system-tuning`.
- **`logo.png` / animation frames** for the Plymouth theme — placeholder
  only, actual art not created.
- **RT kernel package/`.deb`** — user has this already on their own
  board; just needs to be dropped in or the apt method filled into
  `01-realtime-kernel/00-run.sh`'s commented-out Method A/B.

## Things intentionally left as open decisions for the user, not resolved

- Rust (or other compiled language) for the UI layer — legitimate for UI
  smoothness/footprint, not for latency; user hadn't decided as of last
  message.
- Whether to eventually move to an I2S DAC HAT instead of USB audio, to
  remove the USB polling-interval floor.
- Exact `hw:N` ALSA device index in `jack.service`'s `ExecStart` —
  currently a placeholder (`hw:0`), needs the user's actual audio
  interface identifier.

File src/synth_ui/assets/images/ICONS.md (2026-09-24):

# Icons

`settings.png` — the "settings" icon from Google's
[Material Design Icons](https://github.com/google/material-design-icons),
licensed under the **Apache License 2.0**.

Taken from `png/action/settings/materialicons/48dp/2x/baseline_settings_black_48dp.png`
and recoloured white (alpha preserved), scaled to 48x48, for drawing on the dark
header. The source glyph is unmodified in shape.

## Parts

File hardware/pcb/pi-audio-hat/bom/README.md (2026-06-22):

# pi-audio-hat — Board BOM

This folder holds the **component-level** bill of materials for the `pi-audio-hat`
board — every part placed on the PCB (DAC IC, passives, transformer, connectors).

Do not hand-edit this; generate it from the KiCad schematic so it stays in sync:

- **CSV (for ordering):** KiCad → Schematic Editor → Tools → *Generate BOM* →
  export as `pi-audio-hat-bom.csv` in this folder.
- **Interactive HTML (for hand-assembly):** the [iBOM](https://github.com/openscopeproject/InteractiveHtmlBom)
  plugin → export `ibom.html` here.

The board itself is one line item in the project-level [BOM](../../../BOM.md).

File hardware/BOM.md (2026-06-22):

# Bill of Materials

Master parts list to build one MIDI instrument. Quantities are per unit.

Prices are rough placeholders (USD) — update with your actual sources. For the
components *on* the custom audio board, see the board-level BOM:
[pcb/pi-audio-hat/bom/](pcb/pi-audio-hat/bom/). Wiring/pinout reference lives in
[../CLAUDE.md](../CLAUDE.md) (Hardware section).

## Core electronics

| Qty | Component | Spec / Notes | Source / Part # | Approx. Cost |
|-----|---|---|---|---|
| 1 | Raspberry Pi 4 Model B | 4GB recommended (2GB min; 8GB for large sample sets) | TBD | ~$100 |
| 1 | microSD card | 32GB+, A1/A2, Pi OS Lite 64-bit | https://a.co/d/0dI9rsD4 | ~$10 |
| 1 | PCM5102A I2S DAC module | Teyleten Robot PCM5102A; SCK pad shorted to GND | https://a.co/d/094ECi6M | ~$13 (for 3) |
| 1 | `pi-audio-hat` carrier board | Custom PCB that mounts the PCM5102A module onto the Pi; components in PCB BOM | see PCB BOM | TBD |
| 2 | Audio transformer | 600:600 for audio isolation and balanced conversion | https://a.co/d/03pa9yuA | ~$10 (for 10) |

## Display & input

| Qty | Component | Spec / Notes | Source / Part # | Approx. Cost |
|-----|---|---|---|---|
| 1 | Touchscreen | 4.3", 800×480, ft5x06 capacitive controller | https://a.co/d/042zTxz3 | ~$45 |
| 1 | USB MIDI keyboard | Class-compliant USB MIDI | user-supplied | — |

## Enclosure & mechanical

| Qty | Component | Spec / Notes | Source / Part # | Approx. Cost |
|-----|---|---|---|---|
| 1 | Enclosure | 3D-printed, see [enclosure/enclosure.stl](enclosure/enclosure.stl) | self-printed | filament |
| 1 | Heatsink + fan | For Pi 4 — prevents thermal throttling under sustained audio load | TBD | ~$8 |
| — | Fasteners | M2.5 standoffs/screws for Pi + board + screen mounting | TBD | ~$5 |

## Wiring & connectors

| Qty | Component | Spec / Notes | Source / Part # | Approx. Cost |
|-----|---|---|---|---|
| 2 | XLR male socket | male. one left, one right for balanced output | TBD | ~$3 |
| 1 | Midi female socket |
| 1 | switch | ground lift switch |
| 1 | usb-c power port | Could be any one, but this one was measured to fit | 
| 1 | usb-c vertical breakout board |
| 1 | Header pins / socket | To seat the PCM5102A module on the `pi-audio-hat` and the HAT on the Pi's 40-pin GPIO | TBD | ~$3 |

---

**Notes**
- The `pi-audio-hat` is a **carrier/mount** for the PCM5102A module — you need
  both. The module provides the DAC; the HAT seats it on the Pi and carries the
  board's own components (listed in the PCB BOM).
- DAC wiring (BCK/DIN/LCK → GPIO18/21/19) and boot config (`dtoverlay=hifiberry-dac`)
  are documented in [../CLAUDE.md](../CLAUDE.md), not duplicated here.

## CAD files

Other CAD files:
hardware/enclosure/enclosure5.stl
hardware/enclosure/enclosure43.stl
hardware/enclosure/enclosure43.f3d
hardware/enclosure/enclosure5.f3d

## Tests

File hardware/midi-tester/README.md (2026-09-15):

# MIDI test source

A microcontroller that plays the same notes the same way every time, so the
latency question can be answered with numbers instead of "that felt late."

Playing by hand and watching a terminal can't separate a 5 ms path from a 50 ms
one, can't tell a dropped note from a fumbled one, and can't be repeated
identically after a config change. This can.

## Which board

**Use the Raspberry Pi Pico.** It is the only one of the two that can drive
*both* transports, which is what the investigation actually needs: USB is the
suspect, DIN is the control, and comparing them is only meaningful if the note
schedule is identical on both. One `#define` at the top of the sketch switches
between them; nothing else changes.

The ESP32-C3 works for DIN only. Its USB block is a fixed-function Serial/JTAG
controller and cannot be repurposed into a MIDI device — unlike an S2 or S3,
which have a general USB peripheral. Keep it as a spare.

| | DIN / UART | USB MIDI |
|---|---|---|
| Pi Pico (RP2040/RP2350) | yes | yes — class-compliant, no driver needed |
| ESP32-C3 | yes | no |

## Wiring — DIN

| Pico | ESP32-C3 | Pi |
|---|---|---|
| GP0, pin 1 (TX) | GPIO5 | GPIO15 / pin 10 (RXD0) |
| GND, pin 3 | GND | pin 6 (GND) |

Both ends are 3.3 V logic, so they connect directly. **Do not** route through the
DIN jack's optocoupler, and unplug the DIN jack while testing — otherwise two
things drive the same line.

The C3 pin is not arbitrary: GPIO12–17 are the SPI flash, 18/19 are USB, 20/21
are the UART0 console, and 2/8/9 are boot strapping pins.

## Wiring — USB

A USB cable. That's the point of it.

## Flashing

**Pico**, with earlephilhower's arduino-pico board package. The USB build needs
the TinyUSB stack, which that core already bundles — there is no library to
install, only a different FQBN. Both variants below are known to compile.

```bash
# DIN  (USE_USB_MIDI 0)
arduino-cli compile --fqbn rp2040:rp2040:rpipico .

# USB  (USE_USB_MIDI 1) — note the usbstack option; without it the sketch
# will not find Adafruit_TinyUSB.h
arduino-cli compile --fqbn rp2040:rp2040:rpipico:usbstack=tinyusb .
```

In the IDE the same switch is **Tools → USB Stack → Adafruit TinyUSB**.

To upload, the Pico must be in its bootloader: unplug it, hold **BOOTSEL**, plug
it in, release. It mounts as a drive called `RPI-RP2`; copy the `.uf2` there, or
point arduino-cli at it:

```bash
arduino-cli upload --fqbn rp2040:rp2040:rpipico -p /Volumes/RPI-RP2 .
```

BOOTSEL is only needed to interrupt firmware that is already running. **Flashing
replaces whatever is on the board**, and the original is unrecoverable without
its `.uf2` — check what is on the Pico before wiping it.

**ESP32-C3** (DIN only):

```bash
arduino-cli compile --fqbn esp32:esp32:esp32c3 .
arduino-cli upload  --fqbn esp32:esp32:esp32c3 -p /dev/cu.usbmodem* .
```

The C3 appears as a `usbmodem`/`ttyACM` device, not `ttyUSB` — it has no external
USB serial chip.

Either board starts sending 2 s after power-up and loops forever.

## What it sends

Each pattern is announced by a Program Change so the Pi can label the log.
Every note carries a sequence number (1..127, wrapping) in its **velocity**, so
drops and reordering are visible from the received stream alone — the two clocks
are never compared.

| # | Pattern | What it answers |
|---|---|---|
| 0 | 60 notes, one every 500 ms (30 s) | Is there jitter at rest? |
| 1 | 10 bursts of 16 notes back-to-back, 2 s apart (20 s) | The fast-solo failure, on demand |
| 2 | 500 notes at 40 ms — 25/sec for 20 s | Does it degrade over time? |

One full cycle is about 80 s.

## Measuring on the Pi

Stop everything that holds the MIDI devices open, so the baseline is a quiet
machine:

```bash
sudo systemctl stop synth-ui jack mod-host ttymidi a2jmidid
```

Then read as close to the kernel as userspace can get:

```bash
cd ~/synth/src          # the package lives here; there is no installed copy

# DIN   (USE_USB_MIDI 0)
python3 -m synth_ui.tools.midi_latency --serial /dev/ttyAMA0

# USB   (USE_USB_MIDI 1, Pico)
python3 -m synth_ui.tools.midi_latency --list       # show what's plugged in
python3 -m synth_ui.tools.midi_latency --rawmidi    # uses the only device, or
                                                    # name one: --rawmidi /dev/snd/midiC1D0
```

For the **USB** run the Pico goes in the Pi's USB port, so unplug the keyboard —
that carrier has only one. For the **DIN** run power the Pico from a charger or
laptop instead, leaving the Pi's port free and one less thing in the
measurement.

Both read the device directly: below ALSA's sequencer, below JACK, below
everything in this project. A delay that shows up here is upstream of all of it.
That is the whole point — it says whether to look at our software or at the
kernel and hardware under it.

Output is inter-arrival min/median/p95/max per pattern, the spread, the dropped
count, and peak per-core CPU plus interrupt deltas over the run.

**Read the spread, not the median.** A path that adds a constant 30 ms is
playable; one that swings between 5 ms and 300 ms is not, and that swing is what
this instrument has.

## Interpreting a run

| What you see | What it means |
|---|---|
| Spread in pattern 0 | Sending is exact, so any variation is jitter the path added |
| Drops only in pattern 1 | A buffer overruns under burst — driver or FIFO |
| Spread grows through pattern 2 | Something falls behind and never recovers |
| Clean here but late through JACK | The fault is ours, downstream of this |
| Late here | The fault is below us: the driver, the kernel, or the board |

## Reading the two runs together

This is the comparison the Pico makes possible, and it is decisive either way:

| DIN | USB | Conclusion |
|---|---|---|
| clean | clean | Nothing below us is broken. The fault is in our stack — a2jmidid, ttymidi, JACK, or mod-host — and it is reproducible with this same source feeding the running system. |
| clean | late | USB MIDI specifically: `snd-usb-audio`, xHCI, or the single port on the Waveshare carrier. Also means you have a working instrument today over DIN. |
| late | late | Below both paths — kernel or board. Every USB experiment so far was aimed at the wrong thing, and the stock-kernel swap becomes the next test. |
| late | clean | The UART side, which nothing depends on yet. Move the keyboard to USB and carry on. |

Eight theories have been tried against this bug by ear. Two runs of this settle
which quadrant the fault is in, before any more time goes into guessing.

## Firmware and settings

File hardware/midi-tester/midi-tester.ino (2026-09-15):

// Deterministic MIDI source for latency/drop testing on the pi-synth.
//
// Playing a keyboard by hand and watching a terminal can't tell a 5 ms path
// from a 500 ms one, and can't tell "dropped" from "I fumbled it". This sends
// MIDI on an exact schedule so the Pi side (tools/midi_latency.py) can measure
// arrival spacing and spot missing notes with no human in the loop.
//
// Every note carries a sequence number in its VELOCITY (1..127, wrapping), so a
// dropped or reordered note is detectable from the received stream alone —
// nothing has to be synchronised between the two clocks. We never compare the
// sender's clock to the Pi's; we only compare *intervals*, which is enough to
// see jitter and loss.
//
// ---------------------------------------------------------------------------
// TRANSPORT — set this, and nothing else changes.
//
// The patterns below are deliberately shared by both paths. USB is the suspect
// in the latency bug and DIN is the control, and that comparison is only worth
// something if the two runs differ in the transport and in nothing else.
//
//   0 = DIN / UART  (any board: Pico, ESP32-C3, ESP32)
//   1 = USB MIDI    (Raspberry Pi Pico only — see the board notes below)
//
// Defaults to USB because that is the path under suspicion. DIN is the control
// run; on the Pico it needs jumper wires to the Pi's GPIO header, and the
// ESP32-C3 can stand in for it.
// ---------------------------------------------------------------------------
#define USE_USB_MIDI 1

// --- Board notes -----------------------------------------------------------
//
// Raspberry Pi Pico (RP2040/RP2350) — does BOTH transports, which is why it is
//   the better board for this job.
//   Board package: earlephilhower's arduino-pico ("Raspberry Pi Pico/RP2040").
//   For USE_USB_MIDI 1 you must also:
//     - install the "Adafruit TinyUSB Library"
//     - set Tools -> USB Stack -> "Adafruit TinyUSB"
//   It then enumerates as a class-compliant USB MIDI device: Linux binds it
//   with snd-usb-audio, no driver needed, and it appears as /dev/snd/midiC*D*
//   exactly as the keyboard does.
//   DIN wiring: GP0 (pin 1) -> Pi GPIO15 (pin 10); GND (pin 3) -> Pi pin 6.
//
// ESP32-C3 — DIN only. Its USB block is a fixed-function Serial/JTAG
//   controller and cannot be repurposed into a MIDI device.
//   DIN wiring: GPIO5 -> Pi GPIO15 (pin 10); GND -> Pi pin 6.
//   GPIO5 because GPIO12-17 are the SPI flash, 18/19 are USB, 20/21 are the
//   UART0 console, and 2/8/9 are boot strapping pins.
//
// For DIN on either board both ends are 3.3 V logic, so connect them directly.
// Do NOT go through the DIN jack's optocoupler, and unplug the jack while
// testing so two things aren't driving the same line.

#if defined(ARDUINO_ARCH_RP2040)
  #define MIDI_TX_PIN 0           // GP0 = UART0 TX
#else
  #define MIDI_TX_PIN 5           // ESP32-C3: see above
#endif

#define MIDI_BAUD 31250           // the MIDI standard rate, as ttymidi expects

#if USE_USB_MIDI
  #if !defined(ARDUINO_ARCH_RP2040)
    #error "USB MIDI here is Pico-only. Set USE_USB_MIDI 0 for the ESP32."
  #endif
  #include <Adafruit_TinyUSB.h>
  Adafruit_USBD_MIDI usb_midi;
#endif

// Patterns, announced with a Program Change so the Pi can segment the log.
enum Pattern { PAT_METRONOME = 0, PAT_BURST = 1, PAT_SUSTAINED = 2, PAT_COUNT };

static const int  NOTE       = 60;    // middle C for all tests
static const int  NOTE_MS    = 20;    // note-on to note-off
static uint8_t    seq        = 1;     // 1..127, carried in velocity

// --- transport -------------------------------------------------------------
// The only two functions that know which wire is in use.

static void midiWrite(const uint8_t *bytes, size_t n) {
#if USE_USB_MIDI
  // tud_midi_stream_write() writes into a fixed TX FIFO and returns how many
  // bytes it actually took. A burst offers bytes far faster than the host
  // drains them, so it WILL come up short, and anything not written is gone.
  //
  // Ignoring that return value made the sender drop ~35% of every burst and
  // report it as a fault on the Pi. Retry until the FIFO accepts the rest,
  // yielding so the USB stack gets to run and drain it.
  size_t sent = 0;
  uint32_t deadline = millis() + 200;   // never wedge the test on a dead link
  while (sent < n && millis() < deadline) {
    sent += usb_midi.write(bytes + sent, n - sent);
    if (sent < n) yield();
  }
#else
  // Serial.write() blocks until the UART buffer accepts everything, so the
  // UART path has never had this problem.
  Serial1.write(bytes, n);
#endif
}

static void midiFlush() {
#if USE_USB_MIDI
  // Adafruit_USBD_MIDI::flush() is a documented no-op ("MIDI Library does not
  // use flush"). Kept for symmetry; what actually drains the FIFO is the core's
  // periodic tud_task() IRQ, which runs regardless of what this loop is doing.
  usb_midi.flush();
#else
  Serial1.flush();
#endif
}

static void send3(uint8_t status, uint8_t d1, uint8_t d2) {
  const uint8_t msg[3] = { status, d1, d2 };
  midiWrite(msg, 3);
}

// --- patterns --------------------------------------------------------------

// One measured note. Velocity is the sequence number, never 0 (a zero-velocity
// note-on is a note-off, which would corrupt the numbering).
//
// holdMs is a parameter and not a constant because it sets a floor on how fast
// notes can be sent: a 20 ms hold makes 20 ms the tightest possible spacing,
// which would quietly turn the burst test into a slow one. Bursts pass 0 and
// let the transport itself set the spacing.
static void sendNote(int holdMs) {
  send3(0x90, NOTE, seq);
  if (holdMs) delay(holdMs);
  send3(0x80, NOTE, 0);
  seq = (seq % 127) + 1;
}

static void announce(uint8_t pattern) {
  const uint8_t msg[2] = { 0xC0, pattern };   // Program Change, channel 1
  midiWrite(msg, 2);
  midiFlush();
  delay(500);                     // a clear gap either side of the marker
}

// 60 notes, one every 500 ms. Steady state: any variation in arrival spacing on
// the Pi is jitter introduced by the path, since these leave exactly on time.
static void metronome() {
  for (int i = 0; i < 60; i++) {
    uint32_t start = millis();
    sendNote(NOTE_MS);
    while (millis() - start < 500) { /* hold the period exactly */ }
  }
}

// 10 bursts of 16 notes sent back to back, 2 s apart. This is the fast-solo
// case — the one that made notes disappear — concentrated and repeatable.
//
// No hold time: the notes go out as fast as the transport carries them (6 bytes
// per note at 31250 baud is ~1.9 ms), so a burst is ~30 ms of solid traffic.
// That is denser than hands can play, which is the point — it is the case that
// breaks. Over USB the same burst leaves faster still, which is fair: the
// question is what each path does with everything we can hand it.
static void burst() {
  for (int b = 0; b < 10; b++) {
    for (int i = 0; i < 16; i++) sendNote(0);
    midiFlush();
    delay(2000);
  }
}

// 500 notes at 40 ms spacing: 25 notes/sec for 20 s. Continuous pressure rather
// than spikes — fast playing, but sustained long enough that a slow leak (a
// buffer filling, a thread falling behind) has time to show.
static void sustained() {
  for (int i = 0; i < 500; i++) {
    uint32_t start = millis();
    sendNote(NOTE_MS);
    while (millis() - start < 40) { }
  }
}

void setup() {
#if USE_USB_MIDI
  usb_midi.setStringDescriptor("pi-synth test source");
  usb_midi.begin();
  // Wait to be enumerated, then a moment more. Notes sent before the host has
  // bound the device are discarded silently, and would read here as drops.
  while (!TinyUSBDevice.mounted()) delay(10);
  delay(2000);
#else
  #if defined(ARDUINO_ARCH_RP2040)
    Serial1.setTX(MIDI_TX_PIN);
    Serial1.begin(MIDI_BAUD);
  #else
    Serial1.begin(MIDI_BAUD, SERIAL_8N1, -1 /* no RX */, MIDI_TX_PIN);
  #endif
  delay(2000);                    // let the Pi side start capturing
#endif
}

void loop() {
  for (uint8_t p = 0; p < PAT_COUNT; p++) {
    announce(p);
    switch (p) {
      case PAT_METRONOME: metronome(); break;
      case PAT_BURST:     burst();     break;
      case PAT_SUSTAINED: sustained(); break;
    }
    delay(3000);                  // silence between patterns
  }
}

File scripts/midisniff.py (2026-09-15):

#!/usr/bin/env python3
"""midisniff.py — dump raw MIDI bytes arriving on the DIN jack (UART0 / GPIO15).

A bring-up and fault-isolation tool, not part of the running system. It answers
one question: *are valid MIDI bytes reaching the board at all?* — which separates
a wiring/opto-isolator fault from a fault above it in ttymidi, JACK, or the UI.

Why this exists rather than `stty` + `hexdump`: MIDI's 31250 baud is not a
standard termios speed, and GNU stty rejects it outright ("invalid argument").
The only interface that expresses it is a raw TCSETS2 ioctl with BOTHER, which
is what ttymidi itself uses — so this reproduces ttymidi's exact serial setup
while involving neither ttymidi nor a running JACK server.

It also holds the port open across configure-and-read: termios settings revert
to the driver default when the last fd closes, so setting the rate in one
process and reading in another silently gets you 9600 and garbage.

Usage, on the Pi (needs no venv — stdlib only; 'synth' is in the dialout group):

    python3 ~/synth/scripts/midisniff.py

Play the DIN keyboard during the listen window. Expect note-on triples that
track what you play (90 3c 64 ...), and possibly a steady drip of fe (active
sensing) even at rest. Bytes that don't track your playing mean the achieved
baud is wrong -- add dtoverlay=midi-uart0-pi5 and switch ttymidi.service to
-b 38400. No bytes at all means wiring or the opto-isolator (check DIN pins
4/5 first), not baud. See docs/engine-architecture.md, "MIDI ingress".
"""

import fcntl
import os
import select
import struct
import sys
import time

# asm-generic ioctls: struct termios2, which (unlike termios) carries explicit
# c_ispeed/c_ospeed fields and so can express an arbitrary baud rate.
TCGETS2, TCSETS2 = 0x802C542A, 0x402C542B
BOTHER, CBAUD = 0o010000, 0o010017          # "speed is in c_ispeed/c_ospeed"
CS8, CREAD, CLOCAL = 0o000060, 0o000200, 0o004000
VTIME, VMIN = 5, 6                          # indices into c_cc
# struct termios2 layout: 4x tcflag_t, c_line, c_cc[19], c_ispeed, c_ospeed
CC_OFFSET, SPEED_OFFSET, TERMIOS2_SIZE = 17, 36, 44

DEVICE = os.environ.get("MIDI_TTY", "/dev/ttyAMA0")
RATE = int(os.environ.get("MIDI_BAUD", "31250"))
SECONDS = int(os.environ.get("MIDI_SECONDS", "30"))


def open_raw(device: str, rate: int) -> int:
    """Open `device` in raw mode at an arbitrary baud rate. Returns the fd."""
    fd = os.open(device, os.O_RDONLY | os.O_NOCTTY)
    buf = bytearray(TERMIOS2_SIZE)
    fcntl.ioctl(fd, TCGETS2, buf, True)
    # Raw: no input/output processing, no line discipline, no echo. Reads
    # return as soon as one byte is available (VMIN=1, VTIME=0) rather than
    # blocking for a newline.
    struct.pack_into("IIII", buf, 0, 0, 0, CS8 | CREAD | CLOCAL | BOTHER, 0)
    buf[CC_OFFSET + VTIME] = 0
    buf[CC_OFFSET + VMIN] = 1
    struct.pack_into("II", buf, SPEED_OFFSET, rate, rate)
    fcntl.ioctl(fd, TCSETS2, buf, True)

    fcntl.ioctl(fd, TCGETS2, buf, True)
    got = struct.unpack_from("II", buf, SPEED_OFFSET)
    if got != (rate, rate):
        print(f"warning: asked for {rate} baud, port reports {got}", file=sys.stderr)
    return fd


def main() -> int:
    try:
        fd = open_raw(DEVICE, RATE)
    except OSError as e:
        print(f"cannot open {DEVICE} at {RATE} baud: {e}", file=sys.stderr)
        return 1

    print(f"listening on {DEVICE} at {RATE} baud for {SECONDS}s "
          f"-- play the DIN keyboard", flush=True)
    deadline, total = time.time() + SECONDS, 0
    while time.time() < deadline:
        if select.select([fd], [], [], 0.5)[0]:
            data = os.read(fd, 64)
            total += len(data)
            print(" ".join(f"{b:02x}" for b in data), flush=True)

    print(f"\n{total} bytes received")
    if total == 0:
        print("nothing arrived -- suspect wiring/opto-isolator, not baud")
    return 0


if __name__ == "__main__":
    sys.exit(main())

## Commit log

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2026-06-17 better voices. lfs for hardware files
    [enclosure.f3d, enclosure.stl]
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2026-07-15 new hardware
    [enclosure.f3d, enclosure.stl, enclosure43.f3d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]
2026-07-15 Add custom pi-gen OS image build; retire setup.sh
    Provision a pi-synth unit by flashing a custom Raspberry Pi OS image instead of
    running setup.sh on a stock Lite card.
    - os-image/: pi-gen (submodule, pinned to bookworm-arm64) plus stage-pi-synth
    stages 00-06 that bake in the RT kernel, the JACK/engine stack (mod-host and
    sfizz built from source), boot config (HiFiBerry DAC, CPU isolation), the app,
    the seven systemd services, and RT tuning.
    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
2026-07-15 Convert pi-gen from git submodule to a fetched build dependency
    pi-gen is a clone-and-run build tool we never modify, needed only when building
    an image. Treating it as a submodule taxed every clone with submodule ceremony
    for no benefit (we keep it pristine and copy config in / mount the repo).
    build.sh now fetches pi-gen on demand, pinned to the exact tested commit
    (d7a31c6, bookworm-arm64), into a gitignored os-image/pi-gen/. Reproducibility
    is preserved by the pin in build.sh; the submodule gitlink and .gitmodules are
    removed, so cloning no longer needs --recursive / git submodule update.
    Docs (os-image/README.md, build.sh header, HANDOFF divergence note) updated.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
2026-07-15 Add audio-device discovery + selectable JACK card, with recovery
    AudioDevices (clients/audio_devices.py) enumerates ALSA playback cards from
    `aplay -l` by stable id and resolves the effective device by precedence
    (saved -> HiFiBerry -> first -> none). scripts/start-jack.sh becomes
    jack.service's ExecStart: it applies that precedence at boot and falls back to
    jackd's dummy backend if no card is present, so jackd and the UI always come up
    and the user can recover from a missing/renamed card. Selection persists in
    ~/.synth-audio-device (config AUDIO_DEVICE_FILE), written by the UI.
    Service coupling for runtime card switching (restart jack):
    - mod-host: PartOf=jack.service (cycles with a jack r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
2026-07-16 Add Engine layer: ProcessEngine / ModHostEngine over systemd + mod-host
    Engine ABC with a uniform interface (start/stop/load/is_ready/panic/midi_port/
    audio_out_ports) over two backings:
    - ProcessEngine (fluidsynth/setBfree/pianoteq): start/stop = systemctl; RT comes
    from the unit file, not Python.
    - ModHostEngine (sfizz/dexed): add/remove/param over mod-host's socket. sfizz and
    dexed share mod-host's one plugin slot + stable ports, so switching between them
    is an in-place plugin swap (key "modhost"), not a JACK re-patch.
    Ports are discovered live via JackGraph (client+type+direction) — no hardcoded
    names. EngineContext bundles shared deps for uniform construction; ENGINE_REGISTRY
    m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
2026-07-16 Rewrite EngineManager on the Engine layer; retire the shell scripts
    EngineManager now composes Engine + JackGraph instead of shelling out to
    engine-manager.sh / midi-connect.sh (both deleted). A voice switch:
    - starts the engine (systemctl / mod-host add) and waits for its JACK ports,
    - wires keyboard MIDI AND engine audio -> system:playback. The audio wiring is
    new — it's what makes sfizz/dexed audible; the old shell path only did MIDI.
    - connect-before-disconnect (no silent gap) + panic-before-teardown (no stuck
    notes); same-source switches (fluidsynth SF2->SF2, sfizz<->dexed) reload in
    place with no restart.
    Port names are discovered live via JackGraph — nothing hardcoded. The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
2026-07-16 Add Audio screen: discover + select the ALSA card from the UI
    New AudioScreen (reached via a second "Audio" button in the home header) lists
    playback cards from AudioDevices and highlights the current one. Selecting a card
    calls EngineManager.set_audio_device: persist the choice (~/.synth-audio-device),
    restart the JACK stack onto it (mod-host/a2jmidid cycle via PartOf), wait for the
    stack to return, and rebuild the active voice on the new server — with a
    "Switching audio..." state while it happens (off the UI thread).
    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
2026-07-16 Green the test suite: rewrite stale synth_client tests; ignore KiCad locks
    test_synth_client.py tested a removed API (FluidSynthClient / ctrl.client /
    current_font). Rewrite it against the current stack — SocketClient (raw
    per-command TCP) and FluidSynthController — with mocked sockets. The full suite
    is now green (45 passed).
    Also gitignore KiCad *.lck lock files.
2026-07-17 Phase 3 (increment 1): effects-rack foundation
    EffectsRack (clients/effects_rack.py): an ordered chain of LV2 effects in a
    dedicated mod-host. add/remove/clear re-chain the graph
    (fx[i].out -> fx[i+1].in -> ... -> DAC), tearing down prior wiring first so no
    stale "old last -> DAC" edge lingers; input_ports/output_ports let EngineManager
    route instrument -> rack -> DAC. Python only patches; DSP runs in the fx
    mod-host. 7 mocked tests.
    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
2026-07-17 Image: bake WiFi from a gitignored wifi.env; hide the console on the display
    WiFi (bookworm/NetworkManager-correct — not the obsolete boot-partition
    wpa_supplicant.conf): if os-image/wifi.env exists (gitignored; copy from
    wifi.env.example), stage 07-wifi writes a NetworkManager profile under
    /etc/NetworkManager/system-connections (0600 root) so the Pi joins WiFi on first
    boot. Optional WIFI_COUNTRY / WIFI_HIDDEN.
    Hide the terminal on the display:
    - cmdline console=tty1 -> tty3 (kernel/systemd boot text off the touchscreen).
    - mask getty@tty1 (no login prompt; frees the VT/DRM console for the KMSDRM UI).
    Admin is via SSH.
2026-07-17 Make mod-host on-demand: fixes continuous core-2 XRuns
    Hardware validation found mod-host (always-on since boot) and the active
    process-based instrument engine (e.g. fluidsynth) both pinned to core 2 at
    chrt -f 80 causes continuous JACK XRuns, even with both fully idle — two RT
    clients contending for one isolated core every 2.67ms period. Stopping either
    one took the xrun count to a steady 0.
    mod-host is now started/stopped by EngineManager exactly like the other
    instrument engines: ModHostEngine.start()/stop() manage mod-host.service
    around the existing add/remove-plugin socket calls, it's no longer enabled at
    boot, and PartOf=jack.service is dropped (it would have force-restarted
    mod-ho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
2026-07-17 ModHostEngine: retry the plugin load, not just the socket connect
    Hardware log: mod-host accepts TCP connections before it's actually ready to
    host a plugin (LV2 world scan on startup, now scanning calf/zam/x42/mda too).
    is_connected() alone was a false-positive readiness signal — the first `add`
    right after a fresh start either bounced with an error (resp -101) or got no
    response at all within the socket's own timeout, so a freshly-switched sfizz/
    dexed voice reliably failed to load.
    Retry _ensure_plugin itself (the actual operation that was failing) with a
    short backoff, instead of gating on a weaker "can I open the socket" check.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
2026-07-17 app.py: disable SDL's audio mixer, it was fighting jackd for the DAC
    pygame.init() initializes SDL's full subsystem set including audio, which on
    the Pi opens its own ALSA PCM stream against hw:sndrpihifiberry — effectively
    the only playback device once onboard audio is disabled (dtparam=audio=off).
    That collided with jackd's exclusive use of the same device: continuous ALSA
    underruns logged under synth-ui.service, and no audio reaching the DAC despite
    the JACK graph being correctly wired (fluidsynth-midi -> system:playback).
    This app never plays audio through pygame — every sound path goes through
    JACK. SDL_AUDIODRIVER=dummy (set before pygame.init()) stops SDL from opening
    an audio de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
2026-07-18 fluidsynth-engine: SDL_AUDIODRIVER=dummy, kills 5s XRun/pop
    fluidsynth is linked against SDL2, which spawns a background "SDLHotplugALSA"
    thread that re-enumerates ALSA devices every ~5 seconds. On hardware that
    periodic scan stalled fluidsynth's RT render thread past the JACK deadline,
    producing a burst of xruns and an audible pop every 5 seconds — play-
    independent, and specific to fluidsynth (setbfree isn't SDL-linked, so it never
    popped). Confirmed by pidstat: the SDLHotplugALSA thread present, and the
    render thread's wakeup rate dipping from 375 to ~366 cswch/s on a clean 5s beat.
    fluidsynth outputs via -a jack, so SDL's audio backend is dead weight. Forcing
    it to the dummy driver re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
2026-07-18 start-jack.sh: wait for the ALSA card before falling back to dummy
    Cold-boot race: jack.service starts at sound.target, but the I2S DAC
    (hifiberry-dac overlay) enumerates its ALSA card a beat later. start-jack.sh's
    one-shot card check therefore found nothing at boot, started jackd on the
    silent dummy backend, and never recovered — Restart=always is no help because
    dummy jackd doesn't crash. Symptom: the graph wires up correctly
    (fluidsynth -> system:playback) but those are dummy ports, so the unit boots
    completely silent until a manual `systemctl restart jack`.
    Add a bounded wait (default 15s, SYNTH_JACK_CARD_WAIT override) for at least one
    playback card to appear before running the exist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
2026-07-18 FluidSynthEngine: select the default font instead of reloading it
    Switching to "General MIDI" was loading its ~140 MB soundfont twice off the SD
    card: once when fluidsynth-engine.service cold-starts (it's on the command line
    and must load before the JACK ports register), then again via a TCP `load` in
    FluidSynthEngine.load() — a redundant read that select 0 1 0 0 doesn't even use
    (it selects sfont 1, the startup copy). That second load was the "artificially
    long" switch.
    The startup font is resident as sfont 1 for the process lifetime, so switching
    to the default voice is now just a preset select. samefile() handles default.sf2
    being a symlink to the real font. Other (non-default) fluidsy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
2026-07-18 02-audio-stack: build the sfizz LV2 plugin from sfizz-ui
    The stage cloned sfztools/sfizz, which builds only the core library + a
    standalone JACK client — it never produces an LV2 plugin. So the image shipped
    no sfizz.lv2, and mod-host's `add http://sfztools.github.io/sfizz 0` failed with
    resp -101 (invalid URI). The LV2 plugin lives in the separate sfztools/sfizz-ui
    repo.
    Build sfizz-ui headless (PLUGIN_LV2=ON, PLUGIN_LV2_UI=OFF; JACK/shared/render/
    VST3 off). Verified on hardware: installs /usr/local/lib/lv2/sfizz.lv2 and
    lv2ls reports http://sfztools.github.io/sfizz, matching the URI hardcoded in
    clients/engine.py — no code change needed.
    Also documents that Dexed is still not built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
2026-07-18 start-jack.sh: exclude HDMI audio devices from card selection
    Follow-up to the boot-race fix (6f69bbe): that made jack wait for "any" card,
    but the Pi's HDMI audio devices (vc4hdmi0/1) are always present and enumerate
    BEFORE the I2S HifiBerry DAC at cold boot. So the wait tripped on HDMI, the
    precedence's "first available" fallback grabbed vc4hdmi0, and jackd exited 255
    trying to open it ("Cannot open PCM device alsa_pcm") — cascading a2jmidid and
    mod-host into failure and leaving the unit with no audio stack at all.
    This is a HifiBerry appliance; HDMI audio is never the target. Filter vc4hdmi*
    out of list_cards so the wait correctly blocks until the real DAC appears, the
    fallback never p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
2026-07-19 ModHostEngine: wire MIDI to effect_<instance>:control, not mod-host:midi_in
    Confirmed on hardware: mod-host does NOT forward its shared mod-host:midi_in
    into the hosted plugin, so wiring the keyboard there was a silent dead end
    (effect_0:control had no incoming connection and notes never reached sfizz).
    The plugin's real MIDI input is its own atom/control port,
    effect_<instance>:control — connecting the keyboard to that is what makes it
    sound. Override midi_port to discover under the effect client (same one used for
    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
2026-07-19 03-boot-config: disable HDMI audio (vc4-kms-v3d,noaudio)
    The vc4 KMS driver registers HDMI audio codecs as ALSA playback cards
    (vc4hdmi0/1). This appliance outputs only through the HiFiBerry DAC and its
    touchscreen isn't HDMI, so they're pure clutter — and they enumerate before the
    I2S DAC at boot, which is what crashed jack before start-jack.sh learned to
    filter them. Append ,noaudio to the KMS overlay so they never register. Only
    affects HDMI audio; display is untouched. Idempotent.
2026-07-19 06-system-tuning: stop blocking boot on network-online + trim boot one-shots
    NetworkManager-wait-online.service was the single biggest boot cost (~7s) and
    serves no purpose here — the audio stack needs no network, and waiting can hang
    boot when WiFi is flaky. Disable it (NetworkManager still runs; boot just doesn't
    wait). Also disable the bootloader-EEPROM auto-update check (no surprise firmware
    changes on a fixed appliance) and e2scrub_reap (no LVM). These are boot-time
    one-shots, not runtime/jitter services.
2026-07-19 voices.json: swap Salamander for LivingRoom Upright (light SFZ piano)
    Salamander V3 (641 regions, 16 velocity layers, ~700MB FLAC) can't stream
    cleanly off SD on a 2GB Pi 4 — constant xruns. LivingRoom Upright Micro is a
    4-layer, ~107MB SFZ upright that fits the hardware. Points at a clean-named
    symlink (livingroom-upright.sfz) since the distributed filename has spaces that
    mod-host's patch_set would truncate. Re-add Salamander when NVMe/SSD storage is
    available.
2026-07-23 mod-host: commit cores 2,3 (validated ~180->~65 xruns/min on hardware)
    Codifies tonight's live testing: mod-host expanded from core 2 alone to cores
    2,3 (still no chrt), since a large SFZ's sample streaming/decode work was
    contending with JACK's own callback thread for the single core — a measured
    problem (~180 xruns/min at only 40-60% CPU, confirming RT audio is deadline-
    per-callback bound, not utilization-bound) with a measured improvement
    (~65 xruns/min after the change).
    Also tested and explicitly rejected: re-adding chrt (priority-inverts against
    JACK's own callback thread, made things catastrophically worse) and extending
    onto core 0 (that's where isolcpus/nohz_full deliberately ro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
2026-07-24 os-image/.gitignore: match kernel artifacts at any depth under kernel/
    Kernel artifacts are about to gain a board-target subdirectory (kernel/cm5/,
    alongside the existing flat kernel/kernel8.img layout for the Pi 4). The old
    patterns (kernel/*.img etc.) only match direct children of kernel/, so a new
    subdirectory's artifacts would have been untracked-but-not-ignored -- one
    git add -A away from accidentally staging a multi-hundred-MB kernel/modules
    tree. kernel/**/*.img (etc.) matches at any depth, including zero (still
    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
2026-07-24 os-image: add PI_SYNTH_BOARD to build for CM5 alongside pi4
    Threads a board selector (PI_SYNTH_BOARD, default pi4) through the build
    pipeline so the same os-image/ builds either target:
    - build.sh: validates board-specific kernel artifacts, passes PI_SYNTH_BOARD
    into the Docker container via PIGEN_DOCKER_OPTS -e (mirrors how PI_SYNTH_SRC
    already crosses the host/container boundary).
    - config: re-exports PI_SYNTH_BOARD for stage scripts (they run as child
    processes, same reason PI_SYNTH_SRC is exported); IMG_NAME branches on it so
    a pi4 and a cm5 build never collide in deploy/.
    - 01-realtime-kernel: installs from the board's kernel directory to the
    board's actual boot filename -- k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
2026-07-25 03-boot-config: cm5 DSI touchscreen overlay, board-conditional
    Confirmed on hardware: on BCM2712 (CM5's SoC, via its RP1 DSI driver),
    display_auto_detect alone hung/crashed the board with this panel connected
    -- required a re-flash to recover. Disabling auto-detect and specifying the
    panel's overlay explicitly is what's actually proven stable (also the common
    pattern on this SoC generation even for Raspberry Pi's own official panels).
    Only applied when PI_SYNTH_BOARD=cm5 -- the pi4 build is untouched and keeps
    working via plain display_auto_detect=1, which already works fine on that
    hardware. dtoverlay= is additive: this coexists with vc4-kms-v3d (still
    required as the base KMS driver) and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
2026-07-25 05-services: cm5 SDL_KMSDRM_DEVICE_INDEX=0 drop-in for synth-ui
    Confirmed on hardware: on BCM2712/RP1 (CM5's SoC), DSI and the main GPU/HDMI
    live on separate DRM devices (drm-rp1-dsi vs vc4-drm) -- pi4 has one unified
    device and needs no disambiguation. Without this, SDL's KMSDRM backend only
    ever opened a GPU render node (renderD128), never a primary card node for the
    DSI device, so frames rendered correctly but never reached the physical panel:
    backlit, 800x480 mode negotiated (matches config.py's SCREEN_W/SCREEN_H)
    confirming resolution wasn't the issue, but nothing visible.
    Installed as a systemd drop-in (matching what was live-tested) rather than
    edited into the base synth-ui.service,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
2026-07-25 06-system-tuning: re-enable avahi-daemon for <hostname>.local resolution
    Requested: resolve synth.local (TARGET_HOSTNAME in os-image/config) on boot
    instead of needing to look up the board's IP. avahi-daemon (mDNS) was
    previously disabled alongside bluetooth/ModemManager/etc. as a general
    jitter-reduction sweep, but it does no hardware polling and never touches the
    isolated audio cores (1,2,3) -- it just runs on core 0 with SSH and the rest
    of the non-RT stack, same as it always has. Carved out as an explicit
    exception rather than reverting the whole disabled-services list, so
    bluetooth/ModemManager/triggerhappy/hciuart/cron stay off.
    Also fixes CLAUDE.md's "System Tuning Already Applied" s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
2026-07-26 docs: resolve Phase 3 effects-rack core conflict -- shared mod-host instance
    Effects run in the same mod-host instance as the active instrument (cores 2+3)
    instead of a second process on a dedicated core, resolving the conflict
    flagged in 813a7cb between the original Phase 3 plan and the core allocation
    that fixed the instrument's own xrun problem.
    Reasoning, not just resource contention: instrument -> effects is a serial
    data dependency (effects can't process a period until the instrument's output
    for that period exists), so separate cores never bought parallelism between
    those two stages -- there's no independent work to overlap, unlike mod-host's
    LV2 worker threads (e.g. sfizz's sample s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
2026-07-26 Phase 0: delete the superseded two-mod-host-instance effects design
    mod-host-fx.service (a second mod-host on port 5556/core 3, installed but
    never enabled) is dead: instrument->effects is a serial data dependency, so a
    second process/core never bought parallelism there (docs/engine-architecture.md
    "Effects rack" has the full reasoning, written earlier tonight). Delete the
    unit, drop it from 05-services' install loop, and rewrite effects_rack.py's
    module docstring to describe the actual (single shared instance) design
    instead of the one being replaced.
    First step of "Wire the effects rack into EngineManager + UI" (see
    .claude/plans -- purrfect-orbiting-flamingo.md).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
2026-07-26 Phase 1: don't kill the effects rack when switching away from mod-host
    ModHostEngine.stop() unconditionally stopped mod-host.service on every
    instrument switch away from sfizz/dexed -- which would destroy every loaded
    effect along with the instrument's own slot, directly breaking "persistent
    across instrument switches" once effects actually exist.
    Add EngineContext.mod_host_needed (defaults to always-False, so every
    existing test's behavior is unchanged) and gate the systemctl stop on it.
    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
2026-07-26 Phase 2: wire EffectsRack into EngineManager
    EngineManager now owns an EffectsRack (constructed with its existing
    ModHostClient -- never a second one) and:
    - _wire() routes engine audio to the rack's input when non-empty, instead of
    always going straight to the DAC. The rack's own output->DAC leg is
    untouched (EffectsRack._rechain already owns it).
    - New add_effect/remove_effect/clear_effects/set_effect_param/effects()
    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
2026-07-26 Add EffectsScreen + EffectsCatalogScreen UI (Phase 4)
    Wires the EffectsRack built in Phase 2 into the touchscreen UI: a
    third Header action slot ("Effects") gated on
    EngineManager.effects_available() (only while a mod-host-hosted voice
    is active, per the plan's v1 scope decision), an EffectsScreen showing
    the loaded chain with a per-row remove-X, and an EffectsCatalogScreen
    to browse instruments/effects.json and add entries. Mutations run on a
    background thread with header loading/error feedback, mirroring the
    existing USBScreen/HomeScreen patterns. No new UI test file added, per
    the plan's own note: no screen in this codebase has UI-level tests
    yet, so behavior stays covered at the EngineMa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
2026-08-15 ready to go
    [pi-audio-hat.kicad_pcb, pi-audio-hat.kicad_sch]
2026-08-26 parking for rig library
    [enclosure5.f3d, enclosure5.stl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]
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2026-09-16 screen brightness and fixed velocity flag
2026-09-28 Protect sets against power cuts; back up and restore via USB
    - Every state file goes through storage.write_atomic (temp, fsync, rename).
    - The sets store keeps three rolling backups, at least 5 min apart. A store
    that won't parse is set aside as .corrupt-<time> and the newest good backup
    loaded; previously bootstrap saved a default set straight over it.
    - A banner on the home screen says when sets were recovered.
    - Settings > Backup writes synth-sets-<host>-<date>.json to a USB stick and
    restores (adds) the newest one. Same format as the web editor's Export;
    both now share SetLibrary.import_sets.
    - udev rule automounts USB sticks at /media/synth/<dev>, idle-unmounted, so
    the USB sc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
2026-09-29 Add 19 sampled voices: Rhodes, Wurlitzer, Clavinet, No-Budget Orchestra
    - install_library unpacks zip archives (with the same path-escape and
    symlink filtering as tar) and sends a User-Agent: bandshed.net answers
    Python's default with 403.
    - New libraries: rhodes, wurlitzer, clavinet, nbo (No-Budget Orchestra 2).
    - voices.json: Stereo Rhodes, Wurlitzer, Hohner Clav; string and brass
    sections, choir, solo strings, brass and woodwinds, harp. Categories match
    the GM ones so they sit beside them in the picker; names avoid GM names,
    since rigs refer to voices by name.
    - calibrate_levels refuses to run while synth-ui holds mod-host, instead of
    reporting every voice (and the limiter) as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
2026-09-29 Recover from a replugged keyboard and a crashed mod-host by themselves
    Saw Wave (a fixed-velocity rig) went silent and stayed silent. Three causes:
    - The velocity filter remembered which keyboards it had connected, by port
    name. A keyboard that comes back (replugged, switched on, woken from Auto
    Off) has the same name and no connections, so it was skipped: every
    fixed-velocity rig stayed silent until the UI restarted. It now connects
    every keyboard on every wire; JackGraph.connect is idempotent.
    - Nothing re-wired a keyboard that appeared after the rig loaded; the keys
    were dead until a rig change or Settings > Reconnect. KeyboardWatcher looks
    every 2 s for keyboard ports connec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
